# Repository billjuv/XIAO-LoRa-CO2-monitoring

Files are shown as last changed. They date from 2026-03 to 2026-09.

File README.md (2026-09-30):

# XIAO/LoRa/SCD41 CO₂ Monitoring System
> 🍄 One of several related projects. See the full list at **[billjuv.github.io](https://billjuv.github.io)**.

A wireless CO₂, temperature, and humidity monitoring system for mushroom grow operations, using LoRa radio to send sensor data to a central MQTT broker — no WiFi is required on the sensor node. In this project, the remote location is a mushroom grow facility in Nevada, and the local network names and device names used throughout are examples — substitute your own network and device names as appropriate.

---

## Table of Contents

- [Overview](#overview)
- [Bill of Materials](#bill-of-materials)
- [Hardware Setup](#hardware-setup)
- [Firmware](#firmware)
- [LoRa Gateway (OMG)](#lora-gateway-omg)
- [MQTT Data Pipeline](#mqtt-data-pipeline)
- [Node-RED Dashboard](#node-red-dashboard)
- [InfluxDB & Grafana](#influxdb--grafana)
- [SCD41 Calibration (FRC)](#scd41-calibration---frc)
- [OTA Firmware Updates](#ota-firmware-updates)
- [Known Issues & Lessons Learned](#known-issues--lessons-learned)
- [Future Enhancements](#future-enhancements)
  
---

## Overview

This project monitors CO₂ levels in the incubation and fruiting areas of a mushroom grow operation. At this time, three identical sensor units are deployed (though only two are documented below), each transmitting wirelessly over LoRa to a central gateway. The sensor nodes can be run on battery power and need to be moved outdoors for recalibration, or while determining optimal placement. 

**Why LoRa instead of WiFi?**  

WiFi has its challanges in the twin metal shipping containers in this mushroom grow space. I want to test the reliability and range of LoRa (not LoRaWAN) in this situation and hopefully be ready for future growth. Ultimately, I wish to expand this method to more remote areas of the farm as well. **Note:** The LilyGo T3 LoRa32 running OpenMQTTGateway does require WiFi to send the data recieved to the MQTT broker.

**Why Sensirion SCD41 instead of the Atlas Scientific EZO-CO₂?**  

The EZO sensors require lab-grade reference gases for recalibration and proved unreliable in this environment (one of two failed and the other EZO-CO2 sensor readings seem considerably lower than expected). The SCD41 supports Forced Recalibration (FRC) using outdoor air (~425 ppm), making field recalibration practical with just a short trip outside. Cost is also an obvious factor.
**Note:** The SCD41 has a maximum CO₂ reading of 5000 ppm, whereas the Atlas EZO-CO₂ max is 10,000 ppm. This should not be a problem in most cases as you want to keep the CO₂ level in fruiting well below 1000. During incubation, levels of 10,000 to 20,000 ppm are common - which is beyond the EZO's capabilities as well.

### System Architecture

```
[XIAO ESP32S3 + SCD41]
        |
        | LoRa (915 MHz)
        ↓
[LilyGo T3 LoRa32 running OpenMQTTGateway]
        |
        | MQTT (WiFi)
        ↓
[Mosquitto on Raspberry Pi 4]
        |
        ├── Node-RED  (dashboard, FRC commands, watchdog alerts)
        └── InfluxDB  (time-series storage → Grafana)

```

**Why InfluxDB/Grafana instead of Mycodo?** 

[Mycodo](https://kizniche.github.io/Mycodo/) could be installed in place of the InfluxDB/Grafana programs if desired. I started with Mycodo but found, in this operation, Node-RED and Flowfuse Dashboard 2.0 offered all the functionality needed with a better control dashboard on a mobile phone. All I ended up using Mycodo for was the built-in InfluxDB database and graphs. I switched over to stand-alone InfluxDB/Grafana programs for less overhead and prettier graphs.

---

## Bill of Materials

| Component | Part | Source |
|---|---|---|
| MCU + LoRa | Seeed Studio XIAO ESP32S3 + Wio-SX1262 LoRa B2B Kit | [Seeed Studio](https://www.seeedstudio.com/Wio-SX1262-with-XIAO-ESP32S3-p-5982.html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) |
| CO₂/Temp/RH Sensor | Adafruit SCD41 | [Adafruit](https://www.adafruit.com/product/5190?srsltid=AfmBOooh3oM7GaWI46jUPZLEENWeh_0F4iTKuAPATtS-eD_7WIwIb3Oz) |
| Battery Monitor | Adafruit MAX17048 LiPoly / LiIon Fuel Gauge | [Adafruit](https://www.amazon.com/dp/B0D7CL94L2?ref_=ppx_hzsearch_conn_dt_b_fed_asin_title_2&th=1) |
| Battery | 3.7V / 1800mAh LiPo | [Amazon](https://www.amazon.com/YELUFT-Rechargeable-Protection-Compatiable-Development/dp/B0F1J7359H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) |
| LoRa Gateway | LilyGo T3 LoRa32 v1.6.1 (915mHz)| [AliExpress](https://www.aliexpress.us/item/2251832685763835.html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) |
| USB-C connector | Female waterproof Type-C panel mount | [Amazon](https://www.amazon.com/dp/B0D7CL94L2?ref_=ppx_hzsearch_conn_dt_b_fed_asin_title_2&th=1) |
| Waterproof On/Off Switch | 12mm push-on, push-off IP65 | [Amazon](https://www.amazon.com/dp/B0D5CVJGYF?ref_=ppx_hzsearch_conn_dt_b_fed_asin_title_4&th=1) |
| PTFE filter membranes | 20mm, 0.3µm pore, hydrophobic, adhesive-backed | [Amazon](https://www.amazon.com/dp/B09LD119PF?ref_=ppx_hzsearch_conn_dt_b_fed_asin_title_15&th=1) |
| Sensor cable | 22/4 Stranded/Shielded (connectors below added)| Spare shop supplies |
| Sensor cable connectors | 2.54 Female JST XH "Dupont" connectors| [Amazon](https://www.amazon.com/dp/B0897KGG59?ref_=ppx_hzsearch_conn_dt_b_fed_asin_title_108) |
| Enclosure (MCU/battery) | Custom 3D printed box | [See Enclosures.md](Enclosures.md) |
| Enclosure (sensor) | Custom 3D printed box | [See Enclosures.md](Enclosures.md) |

RE: Vendors - Seeed Studio and Adafruit are good sources for products linked, but [Digikey](https://www.digikey.com) carries these items as well at similar pricing, but web pages chosen were better.

> ⚠️ As with any Lora or RF device, be sure to attach the antenna prior to sending any signals. Damage can occur

> ⚠️ Check battery plug polarity (2.0 JST) - all I had received are reversed from normal. Easy to correct, but do it before you let the smoke out.

## Datasheets
[Sensirion SCD4x](Extras/Datasheets/Sensirion_SCD4x_Datasheet.pdf)

[Adafruit-SCD40/41](Extras/Datasheets/adafruit-scd-40-and-scd-41.pdf)

[Adafruit-MAX17048](Extras/Datasheets/adafruit-max17048-lipoly-liion-fuel-gauge-and-battery-monitor.pdf)

---

## Hardware Setup

### Enclosure Design

The sensor unit is split into two separate 3D-printed boxes connected by a short cable (under 1 meter):

Separating the sensor from the electronics keeps heat from the MCU and LoRa module away from the SCD41, which improves temperature reading accuracy.

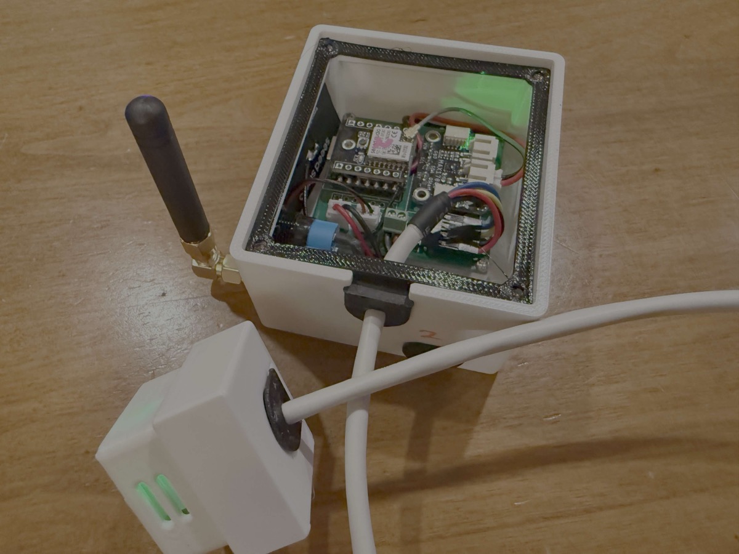
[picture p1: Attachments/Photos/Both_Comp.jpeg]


- **Main box** — contains the XIAO ESP32S3 + Wio-SX1262, MAX17048, and LiPo battery(under PCB). Houses the waterproof USB-C connector for charging and wired power as well as a button to disconnect battery power if total shutdown is desired.

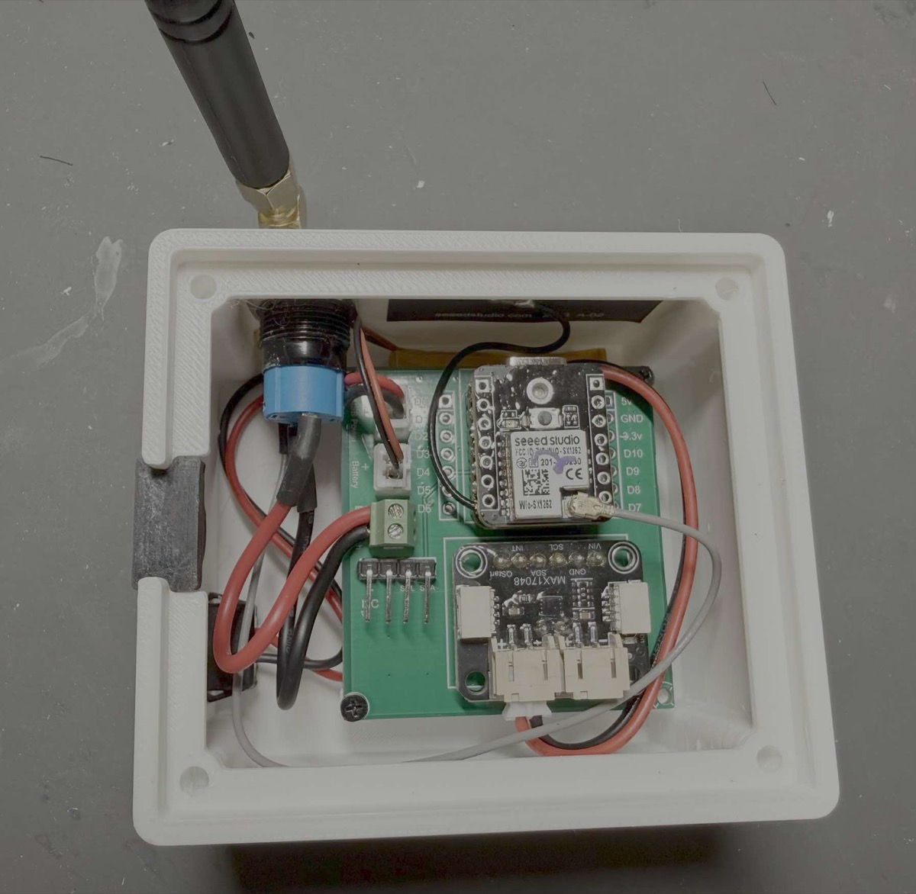
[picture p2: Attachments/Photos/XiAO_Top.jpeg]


(Threaded inserts and lid not shown)

- **Sensor box** — contains the SCD41 only, with a replaceable hydrophobic PTFE membrane filter over the sensor openings (not shown). This box can be positioned for optimal airflow independent of power constraints.

The design of the SCD enclosure takes into account the air flow recommendations from the Sensirion Datasheet.

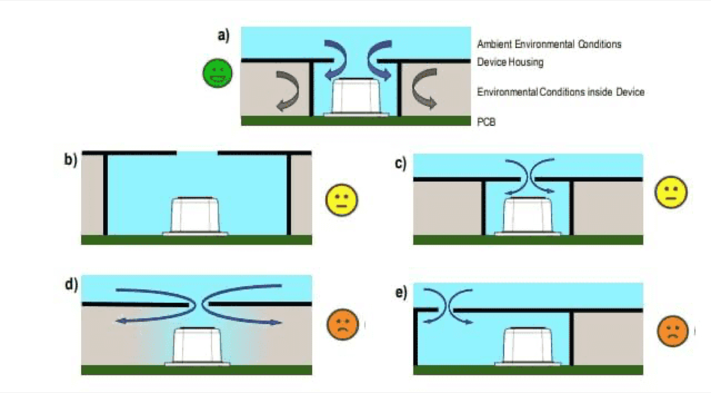
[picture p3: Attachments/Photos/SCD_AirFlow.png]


The foam around the sensor improves the seal (below).

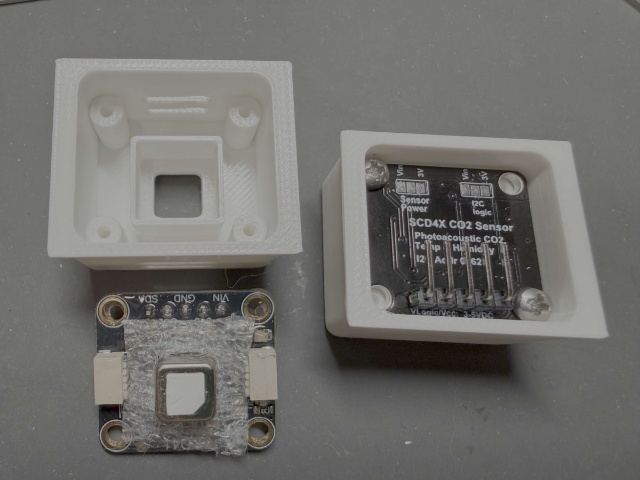
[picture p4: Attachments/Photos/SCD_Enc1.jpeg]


The cable enters from the top to allow hanging with the sensor facing down. The cable grommet shown is 3D printed out of TPU to keep out moisture. Stick-on PTFE membranes are to be placed over vent holes on sides and bottom and replaced as needed.

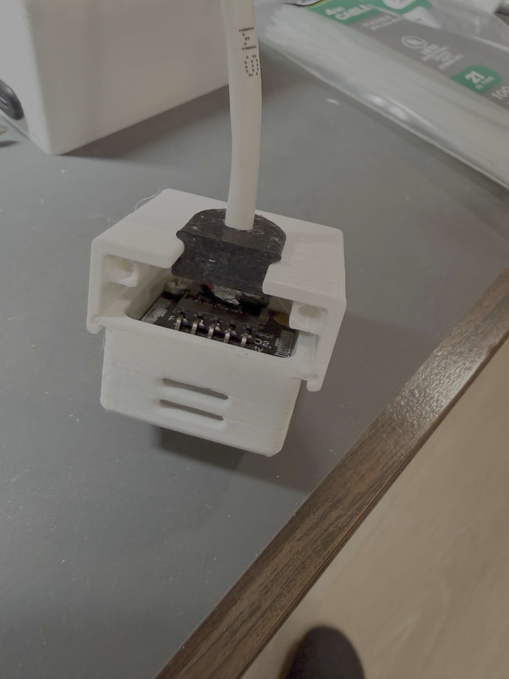
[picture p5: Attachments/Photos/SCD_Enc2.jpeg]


(Threaded inserts and end-cap not shown)

### Pin Mapping

| Function | XIAO ESP32S3 Pin |
|---|---|
| SX1262 NSS (chip select) | 41 |
| SX1262 DIO1 | 39 |
| SX1262 RST | 42 |
| SX1262 BUSY | 40 |
| Status LED | 48 |
| SCD41 SDA (I2C) | 5 (default) |
| SCD41 SCL (I2C) | 6 (default) |
| MAX17048 SDA | 5 (shared I2C bus) |
| MAX17048 SCL | 6 (shared I2C bus) |

> **Note:** The XIAO ESP32S3 + Wio-SX1262 B2B Kit uses a custom pin mapping for the SX1262 that differs from separately purchased boards. The values above are specific to the B2B kit variant.

### Wiring / Schematic

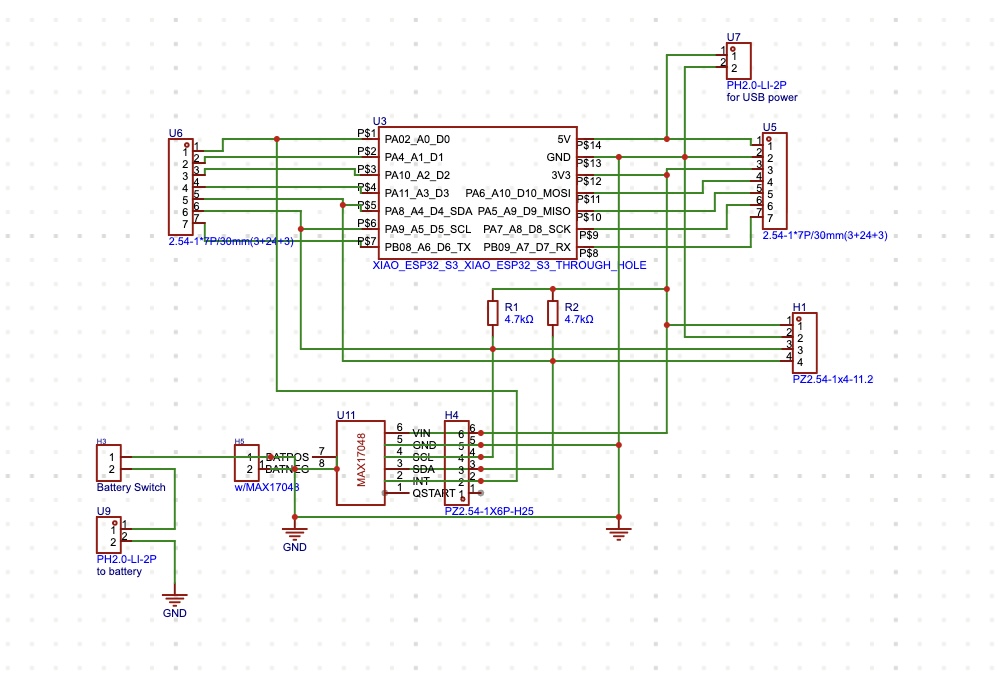
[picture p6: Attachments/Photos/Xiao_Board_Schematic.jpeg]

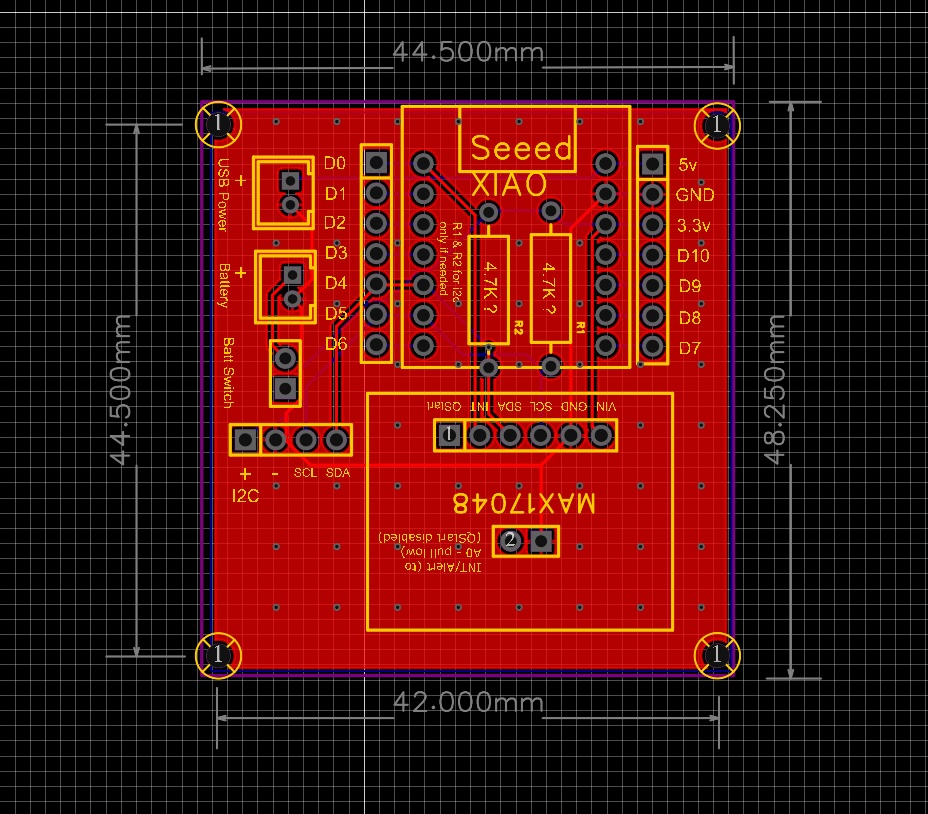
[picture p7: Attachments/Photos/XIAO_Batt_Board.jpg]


> **Note:** Gerber files located in Extras Folder (Extras/Gerber Files/XIAO_Gerber_PCB1.zip)

For other uses, board has additional access to XIAO GPIO pins if needed. Resistors for i2c (under XIAO) usually not needed but available. XIAO MCU board provides built-in battery charging circuitry. **Note:** The above board uses JST 2.0 connectors

- Battery life with the 1800mAh LiPo exceeded 15 hours in testing before recharging. I chose this battery to give enough life during initial optimal placement determination. In practice, the units are typically kept on wired USB-C power when stationary, with battery used mainly for outdoor FRC recalibration runs.

> ⚠️ LiPo batteries often have battery polarity reversed and can cause damage (easy to swap pins for the JST 2.0 connector).

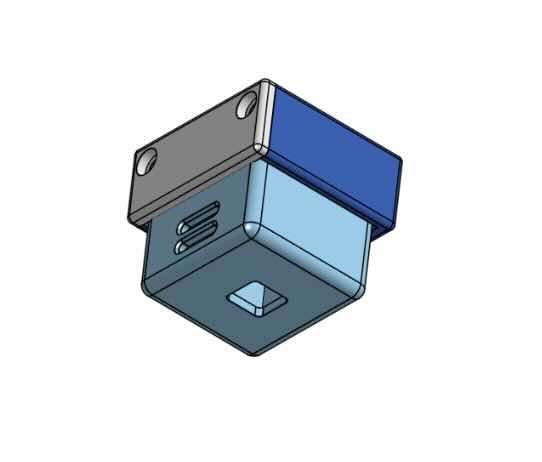
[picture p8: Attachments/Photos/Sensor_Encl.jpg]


### Enclosures & 3D Printing
Both enclosures, the cable grommet, and the lid gasket are custom 3D-printed parts. Full documentation including Onshape links, print settings, materials, and assembly notes is in [ENCLOSURES.md](Enclosures.md).

---

## Firmware

### Prerequisites

- [VSCode](https://code.visualstudio.com/) with [PlatformIO extension](https://platformio.org/)
- A USB-C cable for initial flashing

### Repository Files
- src/main.cpp — Main firmware source
- platformio.ini — PlatformIO build configuration

### platformio.ini

```ini
[env:seeed_xiao_esp32s3]
platform = espressif32@6.6.0
board = seeed_xiao_esp32s3
framework = arduino
monitor_speed = 115200
monitor_filters = time
build_flags =
    -DCORE_DEBUG_LEVEL=5
board_build.stack_size = 16384
board_build.f_cpu = 240000000L
board_build.f_flash = 80000000L
lib_deps =
    Sensirion I2C SCD4x @ ^1.0.0
    bblanchon/ArduinoJson @ ^7.4.2
    sensirion/Sensirion Core @ ^0.7.2
    jgromes/RadioLib @ ^7.5.0
    adafruit/Adafruit MAX1704X @ ^1.0.2
```

### Device Naming

Each unit auto-generates a unique name from its full 6-byte MAC address. Set the base name at the top of `main.cpp`:

```cpp
#define DEVICE_BASE_NAME "LoRa_XIAO1"   // Change for each unit
```

The result will be something like `LoRa_XIAO1_2C02A7D4DB1C`. This name is used as the MQTT `value` field and as the target address for remote commands.

> ⚠️ Using only the last 3 MAC bytes caused duplicate names on boards from the same batch. The full 6-byte MAC is required. Note that the MAC bytes are reported in reverse order — the actual MAC address for the example above would be 1C:DB:D4:A7:02:2C.

### Key Firmware Behaviors

| Behavior | Details |
|---|---|
| Measurement interval | 31 seconds (odd numbers to avoid possible packet collisions between units)*|
| ASC (auto-calibration) | Disabled on every boot and persisted to EEPROM |
| LoRa TX mode | Asynchronous — sensor can still receive commands while transmitting |
| Battery monitoring | MAX17048 detected at startup; if absent, battery fields report 0 / UNKNOWN |
| CPU frequency | Locked to 240 MHz — prevents light sleep from interfering with LoRa interrupts |
| FRC duplicate guard | Ignores repeated FRC commands with the same target within 30 seconds |

*During development, 9 seconds (being a non-round number) was found to make accidental sync less likely to persist even if boards start up at the same time. Time was increased to 31 seconds for production.

---

### Remote Commands (via LoRa)

Commands are sent from Node-RED through the OMG gateway as JSON, targeted by device name:

| Command | JSON payload example |
|---|---|
| Forced recalibration | `{"target":"LoRa_XIAO1_2C02A7D4DB1C","frc":420}` |
| Set temperature offset | `{"target":"LoRa_XIAO1_2C02A7D4DB1C","temp_offset":2.5}` |
| Get temperature offset | `{"target":"LoRa_XIAO1_2C02A7D4DB1C","get_temp_offset":true}` |
| Set altitude | `{"target":"LoRa_XIAO1_2C02A7D4DB1C","altitude":1500}` |
| Get altitude | `{"target":"LoRa_XIAO1_2C02A7D4DB1C","get_altitude":true}` |
| Trigger OTA update | `{"target":"LoRa_XIAO1_2C02A7D4DB1C","ota":true}` |

> The OMG gateway wraps outgoing commands in a `message` field. The firmware handles both wrapped and unwrapped formats for flexibility.

---

### Flashing

1. Connect the XIAO via USB-C
2. Open the project in VSCode/PlatformIO
3. Click **Upload** (or `pio run -t upload`)
4. Open Serial Monitor at 115200 baud to verify startup

---

## LoRa Gateway (OMG)

**Hardware:** LilyGo T3 LoRa32 v1.6.1  
**Firmware:** [OpenMQTTGateway](https://docs.openmqttgateway.com/) v1.8.1

OMG Configuration
The LilyGo T3 LoRa32 was flashed with OpenMQTTGateway v1.8.1 using their web installer — no Arduino IDE or PlatformIO required. Key configuration settings:

| Setting | Value |
|---|---|
| MQTT Broker | MushRmPi (Raspberry Pi running Mosquitto)
| Topic Prefix | OMGhome 
| Gateway Name | OMG_LORA_MOAPA
| WiFi | Required for MQTT connection to broker

The LoRa radio parameters (frequency, SF, bandwidth, etc.) are configured via MQTT commands after flashing — see the OMG LoRa documentation for details. The parameters used in this project are listed in the LoRa Radio Parameters table below.

### LoRa Radio Parameters

Both the sensor firmware and OMG must use identical settings:

| Parameter | Value |
|---|---|
| Frequency | 915.0 MHz (US) |
| Spreading Factor | SF7 |
| Bandwidth | 125 kHz |
| Coding Rate | 4/5 |
| Preamble Length | 8 |
| Sync Word | 0x12 (private network) |
| CRC | Enabled |

> **Sync word 0x12** keeps traffic off from public LoRaWAN networks. Do not use 0x34.

---

## MQTT Data Pipeline

### Incoming Telemetry (OMG → MQTT)

OMG publishes recieved packets to:
```
OMGhome/OMG_ESP32_LORA/LORAtoMQTT
```

Example payload:
```json
{
  "value": "LoRa_XIAO1_2C02A7D4DB1C",
  "co2": 587,
  "temp": 20.77,
  "hum": 35.36,
  "rssi": -38,
  "snr": 10.0,
  "batt_volt": 4.09,
  "batt_percent": 90.2,
  "batt_crate": -3.95,
  "batt_status": "OK",
  "crc_errors": 42
}
```
**Note:** CRC errors in LoRa telemetry
Each sensor unit tracks and reports cumulative CRC errors — packets received but discarded due to radio corruption or collision. Some level of CRC errors is normal, particularly in metal-walled environments. High counts relative to valid packets received may indicate range, interference, or collision issues worth investigating.

### Node-RED Parsed Topics

Node-RED subscribes to the OMG topic, parses by device name, and republishes to per-device topics:

```
LoRa_NodeRed/LoRa_XIAO1_2C02A7D4DB1C/co2
LoRa_NodeRed/LoRa_XIAO1_2C02A7D4DB1C/temp
LoRa_NodeRed/LoRa_XIAO1_2C02A7D4DB1C/hum
LoRa_NodeRed/LoRa_XIAO1_2C02A7D4DB1C/batt_percent
... etc.
```

### Outgoing Commands (Node-RED → OMG → LoRa)

Node-RED publishes FRC and calibration commands to:
```
OMGhome/commands/MQTTtoLORA
```

Wrapped payload format required by OMG:
```json
{"message":"{\"target\":\"LoRa_XIAO1_2C02A7D4DB1C\",\"frc\":420}"}
```

---

## Node-RED Dashboard

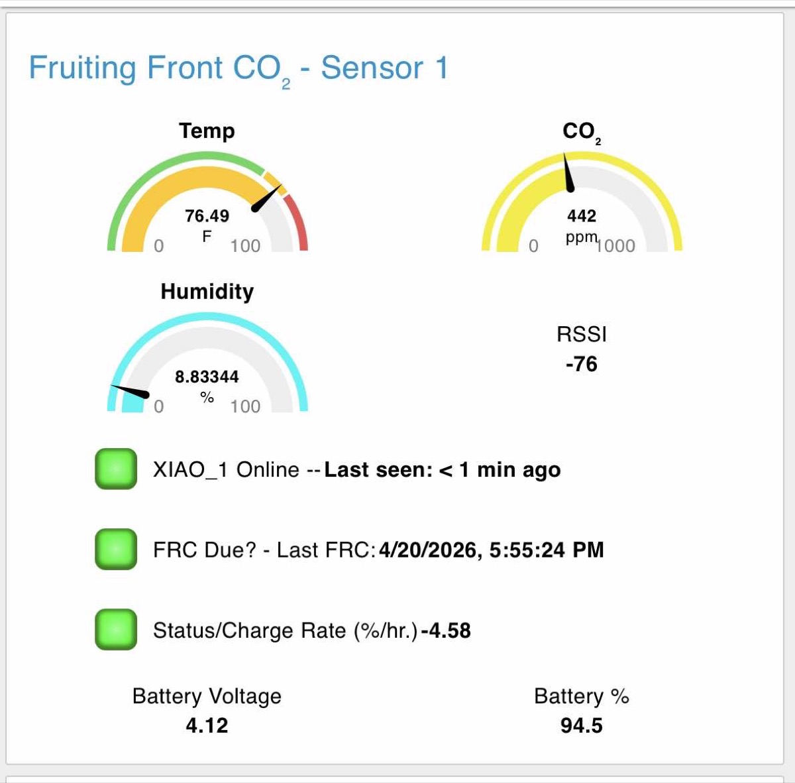
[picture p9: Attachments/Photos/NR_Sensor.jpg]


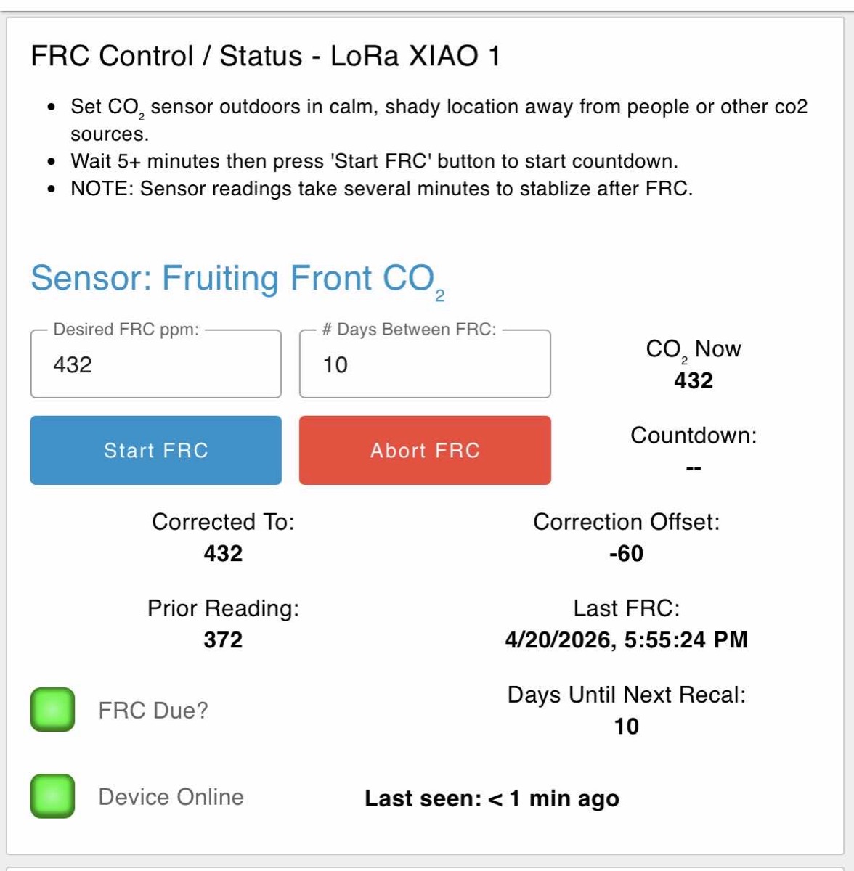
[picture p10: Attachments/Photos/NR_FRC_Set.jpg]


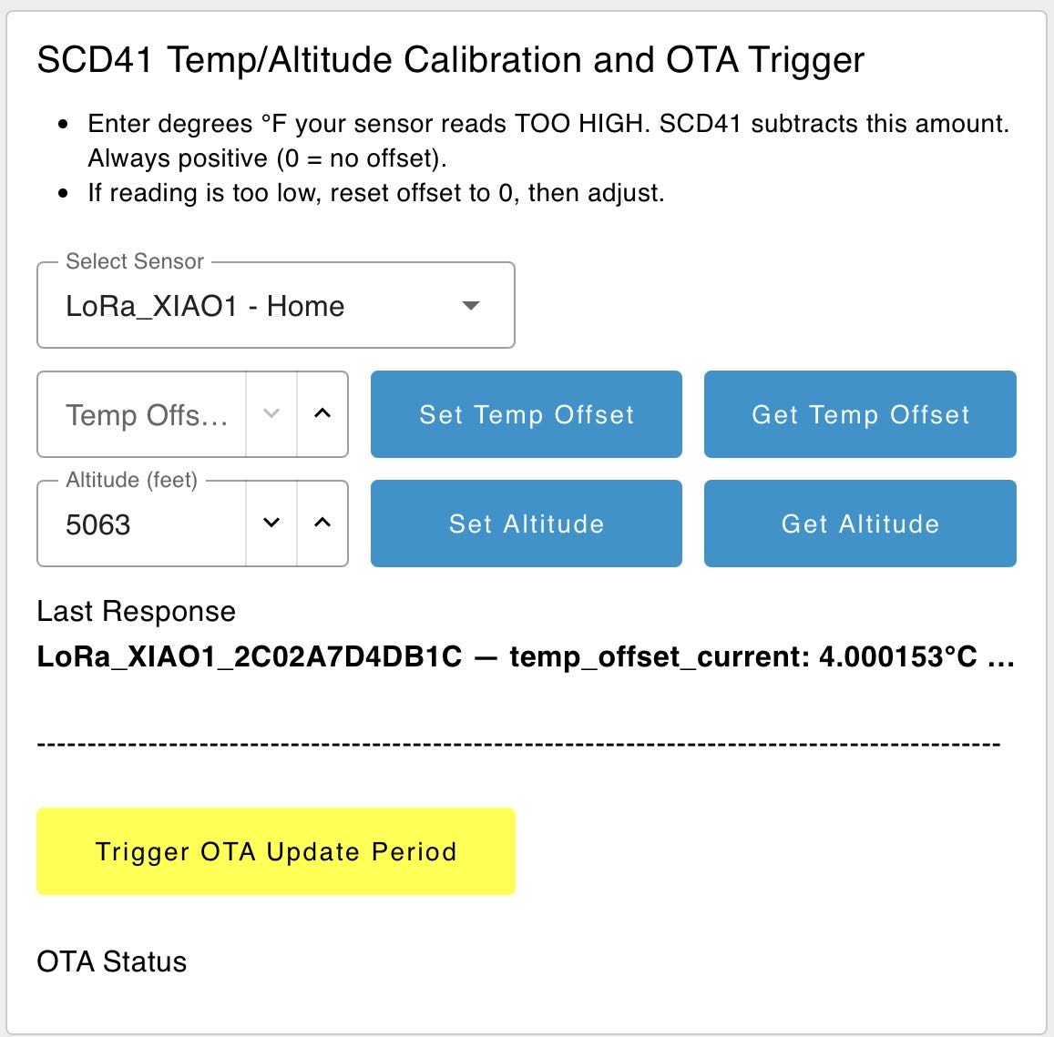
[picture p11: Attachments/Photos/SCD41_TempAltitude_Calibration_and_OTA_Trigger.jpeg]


**JSON files for all three elements are located in "Extras/NodeRED" folder** - 

Import these via Node-RED menu → Import → select file

**Platform:** Node-RED v3.1.7 with FlowFuse Dashboard 2.0

### Features

- **Per-sensor dashboard panels** — separate groups for each CO₂ unit (XIAO1, XIAO2)
- **Live CO₂, temp, and RH readings**
- **Battery status display** — voltage, percent, charge rate
- **FRC calibration controls** — countdown timer, configurable target ppm
- **Multi-send reliability** — FRC command sent 3–4 times at 2-second intervals to account for LoRa packet loss
- **Watchdog status indicator** — LED goes yellow at 5 min silence, red at 10 min, with "Last seen X min ago" text
- **Temperature and Altitude calibration** - Converted for "F" and feet. Separate group as likely only done once
- **OTA trigger button** — select target device from dropdown and press "Trigger OTA Update Period" to initiate remote firmware update

---

## InfluxDB & Grafana

**InfluxDB version:** 1.x  
**Database:** `Sensors`  
**Host:** MushRmPi (Raspberry Pi 4)

### Data Write Method

Data is written to InfluxDB via an **HTTP request node** in Node-RED (not the InfluxDB Out node). This gives direct control over the line protocol format and avoids compatibility issues with InfluxDB 1.x.

### Measurements & Fields

| Measurement | Fields |
|---|---|
| `LoRa_XIAO1_co2` | `co2`, `hum`, `temp` |
| `LoRa_XIAO2_co2` | `co2`, `hum`, `temp` |

> ⚠️ Spaces in InfluxDB measurement names cause silent write failures in line protocol. Use underscores only.

### Grafana

**Sample Grafana Visualization:** (pre-deployment)

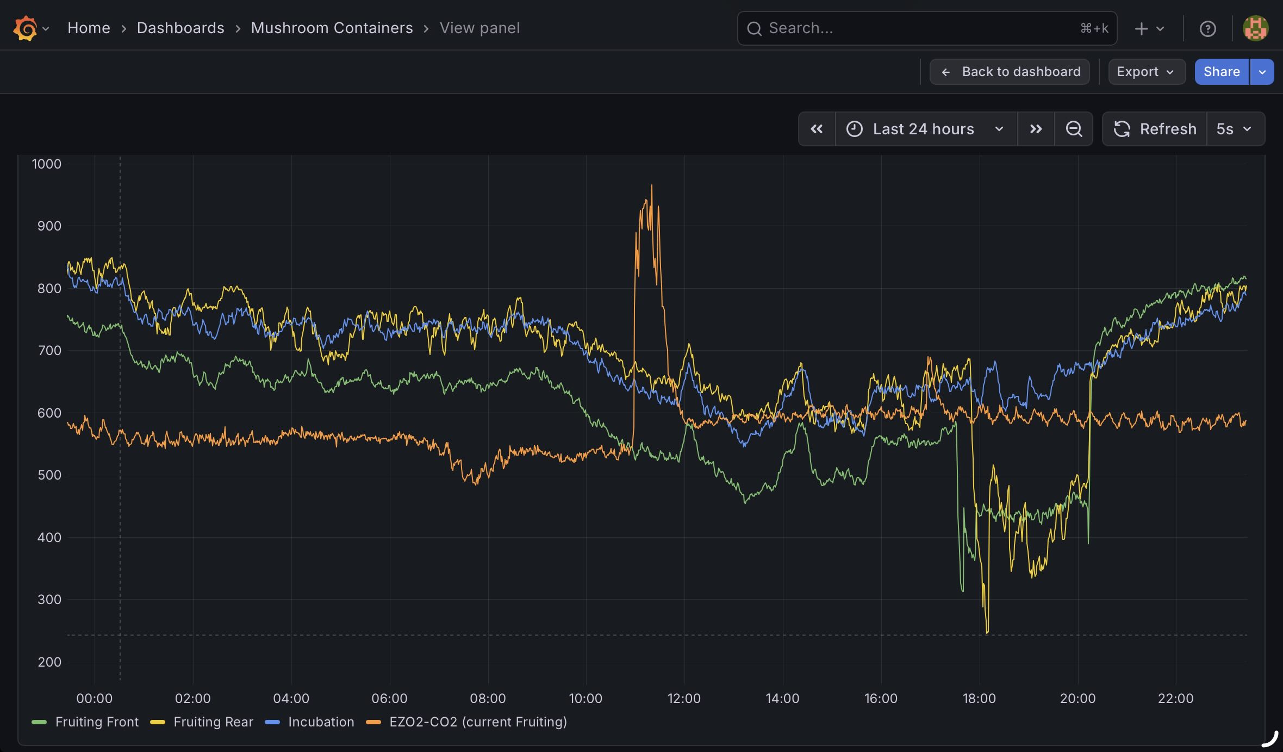
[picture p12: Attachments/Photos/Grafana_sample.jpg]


- Additional visualizations not set up yet, but could include Time-series panels for CO₂, temperature, and humidity per sensor

---

## SCD41 Calibration - FRC
[(See the Calibration.md file for more info)](CalibrationGuide.md)

The SCD41 uses **Forced Recalibration (FRC)** rather than Automatic Self-Calibration (ASC). ASC assumes regular exposure to fresh outdoor air (~420 ppm), which does not happen in a sealed mushroom grow environment. ASC is disabled in firmware and the setting is persisted to EEPROM.

### When to Recalibrate

Recalibrate every **7–10 days**, or any time readings seem inconsistent.

Signs calibration may have drifted:
- CO₂ readings are unusually high or low at rest
- Readings between the two units diverge significantly
- Indoor readings match or exceed expected fruiting-room levels even when the room has been aired out

### FRC Procedure

1. **Check battery** — ensure adequate charge before going outdoors (dashboard battery indicator)
2. **Take the sensor unit outdoors** — find an open area away from vehicle exhaust, HVAC vents, and any CO₂ sources; ideally a light wind
3. **Wait 5–10 minutes** — allow the sensor to equilibrate to outdoor air. Watch the live CO₂ reading on the dashboard stabilize
4. **Note the outdoor CO₂ reading** — typical outdoor air is 420–435 ppm. If possible, check for nearby air monitoring web portals for a current reference value 
5. **Enter the target value** — on the Node-RED FRC panel, enter the current outdoor CO₂ reference value (typically 420 ppm)
6. **Start the countdown** — the dashboard timer will count down and then send the FRC command automatically (sent 3–4 times for reliability)
7. **Confirm success** — the sensor will transmit an `frc_applied: true` confirmation. The dashboard will display the result
8. **Return the sensor** to the grow room and allow 20–30 minutes for readings to stabilize

> **Important:** The sensor must be in stable outdoor conditions *before* the FRC command is sent (5 minutes minimum). The dashboard waits 15 seconds before executing the calibration after receiving the command. The new readings will not be immediately noticable, it will take several minutes to stablilize.

### Reference CO₂ Values

| Condition | Expected CO₂ |
|---|---|
| Outdoor air (typical) | 420–435 ppm |
| Indoor office/home | 600–1000 ppm |
| Mushroom incubation room | 10000–20000+ ppm* |
| Mushroom fruiting room | 500–1500 ppm (species-dependent) |
*Values commonly mentioned on Internet as optimum - unverified

---

## OTA Firmware Updates
[(See the OTA_Guide.md file for full instructions)](OTA_Guide.md)

Once deployed, firmware updates can be pushed to any sensor unit remotely — no USB cable or physical access required. A LoRa command sent from Node-RED triggers a 3-minute WiFi OTA window on the target device. The update is then pushed from a terminal or command prompt using a shell script in the `ota/` folder. The device reboots automatically and resumes normal LoRa operation.

The Node-RED Sensor Calibration dashboard includes a **Trigger OTA Update Period** button that works alongside the existing device selector — select the target unit and press the button. A status confirmation appears on the dashboard when the device has opened its OTA window.

For remote Nevada devices, updates are delivered over Tailscale via the Nevada Raspberry Pi subnet router — no site visit needed.

> See `ota/` folder for per-device upload scripts and `include/secrets.h.example` for WiFi and OTA password configuration.

---

## Known Issues & Lessons Learned

**Duplicate device names from same-batch boards**  
The full 6-byte MAC is used for device naming, but the bytes are reported in reverse order compared to what your router or network tools will show. Using only the last 3 bytes of the MAC address caused two boards to get identical names. Fixed by using the full 6-byte MAC.

**Spaces in InfluxDB measurement names**  
Measurement names containing spaces cause silent write failures in InfluxDB line protocol. Use underscores throughout.

**ASC re-enables after reboot if not persisted**  
`setAutomaticSelfCalibrationEnabled(0)` must be followed by `persistSettings()` or ASC will re-enable on next power cycle.

**FRC must be sent multiple times**  
LoRa packet loss probability is non-trivial. The Node-RED dashboard sends the FRC command 3–4 times at 2-second intervals. The firmware deduplicates these with a 30-second same-target guard.

**LoRa interrupts unreliable on battery without CPU lock**  
Automatic CPU frequency scaling and light sleep interfered with the RadioLib interrupt-driven RX on battery power. Fixed by locking CPU to 240 MHz at boot.

**Simultaneous dropout of both units**  
Both XIAO units occasionally dropped off at the same time. Monitored via a Grafana State Timeline panel. Resolved — was a fluke related to power cycling and battery use at the time, not an ongoing issue.

**OTA via USB boot window not reliable**  
Initial OTA attempts using a timed WiFi window at boot were abandoned due to conflicts between the PlatformIO serial monitor and the USB port during upload. Replaced with LoRa-triggered OTA, which is more reliable and better suited to remote deployment.

---

## Future Enhancements

- Additional sensor units for expanded grow area coverage
- Grafana dashboards for long-term CO₂ trend analysis

---

*Documentation by BillJuv — part of the Nevada mushroom grow monitoring project.*  
*Public project documentation: [billjuv.github.io](https://billjuv.github.io)*

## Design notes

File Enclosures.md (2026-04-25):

# Enclosure & 3D Printing Documentation

This document covers the 3D-printed enclosures, grommets, and gasket used in the XIAO/SCD41 sensor units. CAD files are available on Onshape (public) and exported STEP and STL files are provided in the `CAD` folder of this repository.

---

## Table of Contents

- [Onshape Documents](#onshape-documents)
- [Bill of Materials](#bill-of-materials)
- [Filament & Print Settings](#filament--print-settings)
- [Parts Overview](#parts-overview)
  - [XIAO Control Enclosure](#xiao-control-enclosure)
  - [SCD41 Sensor Enclosure](#scd41-sensor-enclosure)
  - [Cable Grommet & Gasket](#cable-grommet--gasket)
- [Hardware & Assembly Notes](#hardware--assembly-notes)

---

## Onshape Documents

These documents are public and accessible to all Onshape users.
**Owned by:** BillJuv

| Document | Link |
|---|---|
| XIAO/SCD41/MAX17048 PCB | [Open in Onshape](https://cad.onshape.com/documents/322b31f4cb789d0ca7d721ed/w/ee8c4b56b1603b4e20ae5080/e/40f79fbb32535b3e9f26fa67) |
| SCD41_XIAO Enclosure v4.0 | [Open in Onshape](https://cad.onshape.com/documents/fcc89ce80f74fb06b3c73a24/w/bfc54d0a06e95b34f7452eb1/e/d634f8e0859f714640674855) |
| Cable Grommet | [Open in Onshape](https://cad.onshape.com/documents/550715f3ed90ea8fc4acac6c/w/30db51a251d38ff25dbee160/e/a918008760f5b729e8163560) |

---

## Bill of Materials

| Component | Details | Source |
|---|---|---|
| PETG Filament | Overture PETG | [Amazon](https://www.amazon.com/OVERTURE-Filament-Consumables-Dimensional-Accuracy/dp/B07PDV9RC8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) |
| TPU Filament | Overture "High Speed" TPU (95A)| [Amazon](https://www.amazon.com/dp/B08BC654PS?ref=ppx_yo2ov_dt_b_fed_asin_title&th=1) |
| Brass Threaded Inserts (2.5mm) | For lid and cap mounting | [Amazon](https://www.amazon.com/dp/B0FJXLGHY4?ref_=ppx_hzsearch_conn_dt_b_fed_asin_title_1) |
| Screws (2mm x 5mm) | PCB mounting — 2 per unit | [Amazon](https://www.amazon.com/dp/B082XXXRV6?ref_=ppx_hzsearch_conn_dt_b_fed_asin_title_3)|
| Screws (2.5mm x 5mm) | Lid and cap mounting | [Amazon](https://www.amazon.com/dp/B07YS94FFP?ref_=ppx_hzsearch_conn_dt_b_fed_asin_title_5) |

Other parts referenced are found in the Bill of Materials on the main ReadMe
---

## Filament & Print Settings

3D printing was done on a Bambu Labs A1 printer using Overture PETG filament for the enclosures and Overture High Speed TPU (95A) for the grommets and gasket. Bambu slicer profiles used were "Generic PETG" for the PETG and "Bambu TPU 95A HF" for the TPU. Part orientation was set using the Bambu slicer Auto-Orient feature. No supports are required for any part.

> **Note:** TPU cannot be loaded through the AMS — it must be fed directly. Filaments softer than 95A may not feed reliably with this printer.

PETG was chosen for its humidity resistance. TPU was chosen for the grommets and gasket for flexibility and a good seal.

---

## Parts Overview

### XIAO Control Enclosure

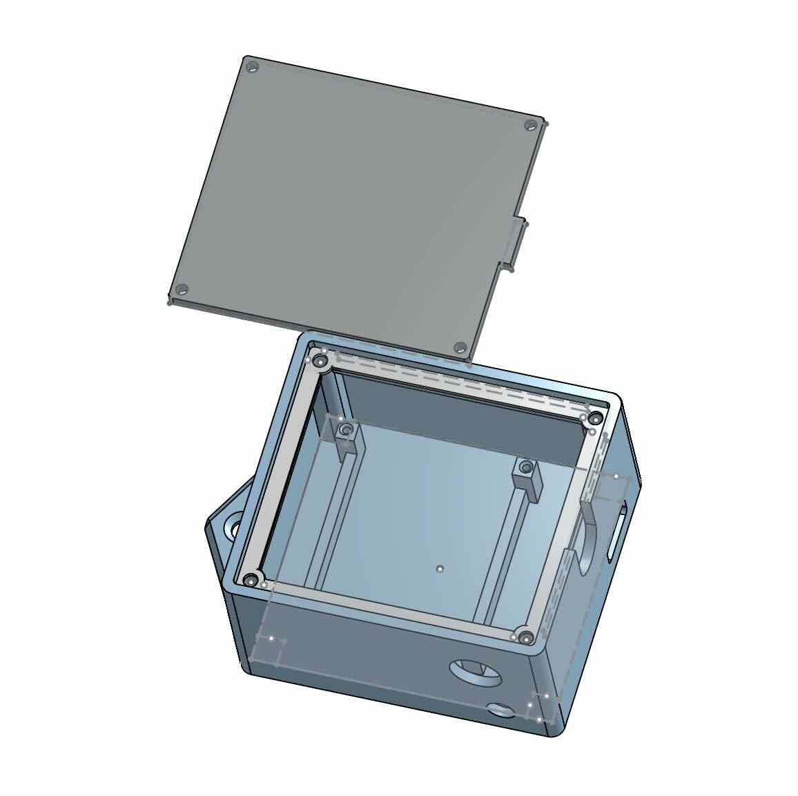
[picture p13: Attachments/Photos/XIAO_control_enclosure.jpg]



This enclosure houses the XIAO ESP32S3 + Wio-SX1262, MAX17048 fuel gauge, and LiPo battery (mounted underneath the PCB). It is designed for humidity resistance, using an IP65-rated on/off switch and a TPU cable grommet for the sensor cable entry. Additional sealing of the antenna connector and USB-C port can be achieved with conformal coating or silicone sealant if needed.

**Design details:**
- The PCB mounting posts are threaded in CAD for 2mm fine-thread screws (2 screws are sufficient)
- The lid is 3mm thick for stiffness and to apply adequate compression to the TPU gasket
- Lid is secured with 2.5mm fine-thread screws into brass threaded inserts
- A mounting tab on the side allows the box to be hung or surface-mounted

> **Note:** "Threaded in CAD" means the holes are modeled with threads — no tap tool is required. Just drive the screw directly into the printed hole.

---

### SCD41 Sensor Enclosure

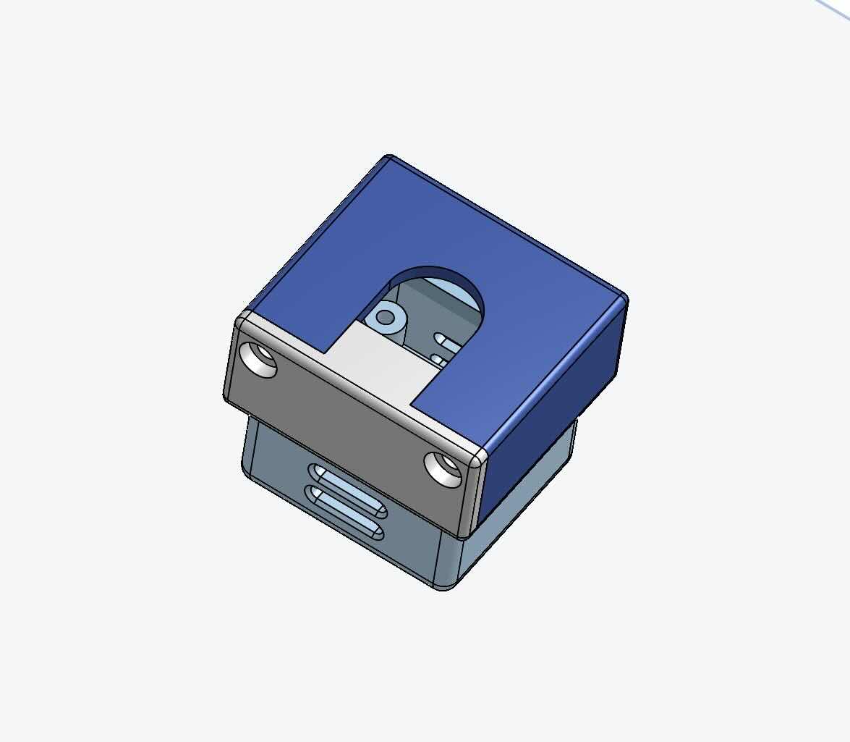
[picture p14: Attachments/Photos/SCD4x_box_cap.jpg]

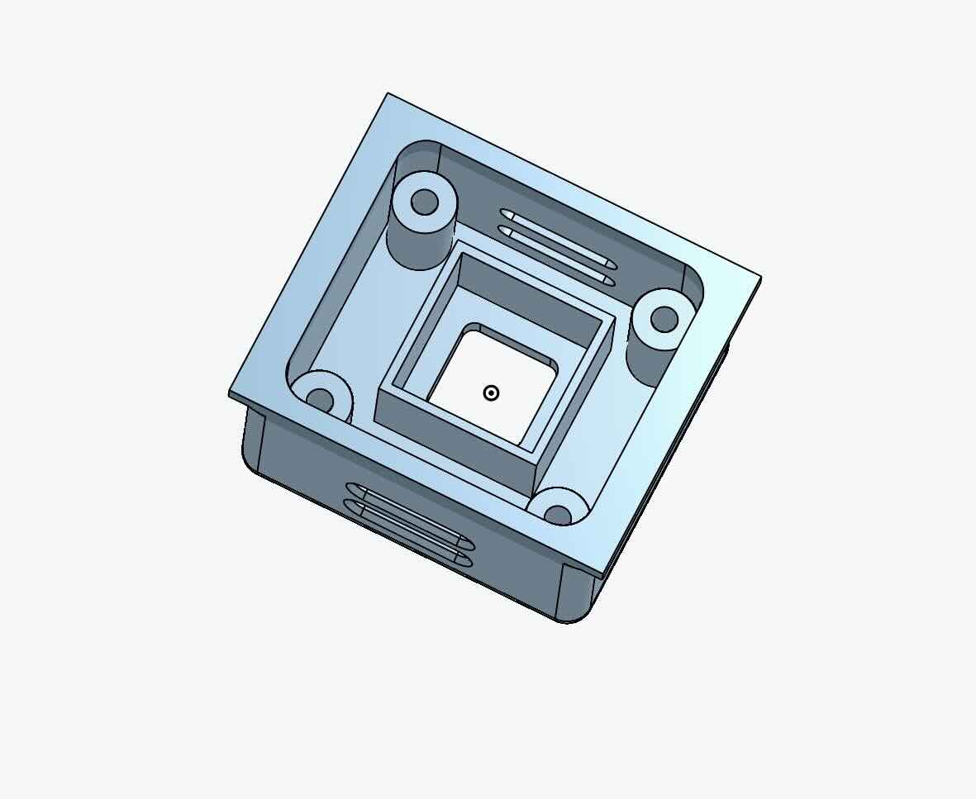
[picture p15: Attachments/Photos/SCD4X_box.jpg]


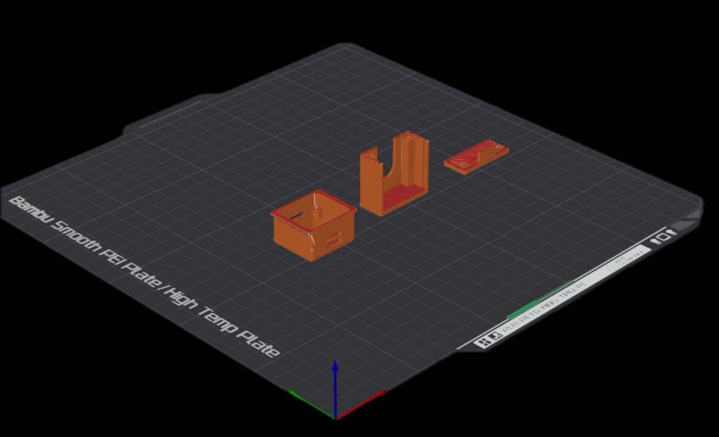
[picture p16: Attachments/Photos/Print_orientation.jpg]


This enclosure is sized to fit the Adafruit SCD41 breakout board. The cap design allows the cable to enter from the top, so the unit can be hung with the sensor facing downward for optimal airflow per the Sensirion datasheet recommendations.

**Design details:**
- Cap face screws are 2.5mm fine-thread into brass threaded inserts in the cap
- PCB post holes are threaded in CAD for 2.5mm fine-thread screws
- Self-adhesive PTFE filter membranes (20mm round) are applied over the vent holes on the bottom and two sides
- A smooth print plate is recommended — clean the surfaces with isopropyl alcohol before applying PTFE membranes
- Replace PTFE membranes as needed

---

### Cable Grommet & Gasket

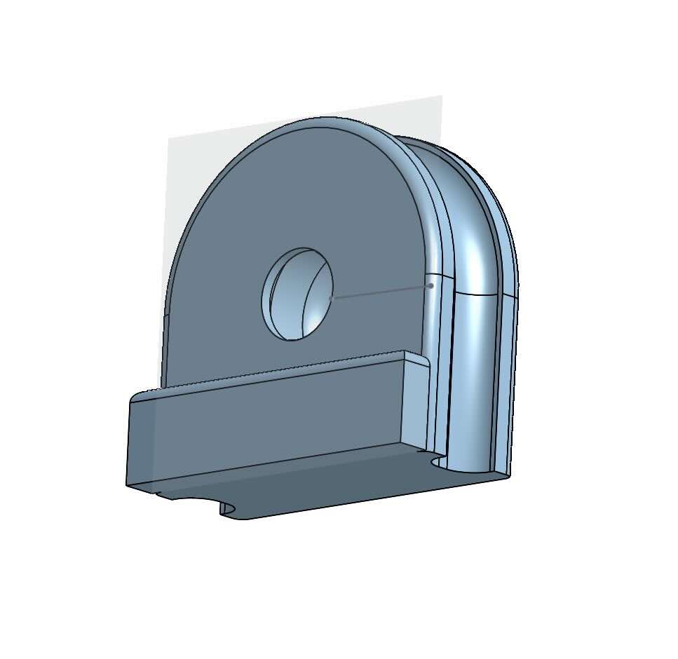
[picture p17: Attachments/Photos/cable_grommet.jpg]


The cable grommet is sized for a 4–5mm diameter cable and is used in both the XIAO control box and the SCD41 sensor cap. A slit is cut across one side of the cable hole with a utility knife to stretch ofer cable after ends are attached. The lid gasket is a separate CAD part within the enclosure assembly. Both are printed in TPU for flexibility and a weather-resistant seal.

---

## Hardware & Assembly Notes

- **Brass inserts** are installed using a soldering iron with a flat or insert tip. Set the iron to around 200–220°C and press slowly and evenly
- **Battery polarity** — LiPo batteries frequently have reversed polarity on JST connectors. Verify polarity before connecting. The JST 2.0 connector pins can be swapped easily with a pin tool
- **PTFE membranes** — clean mounting surfaces thoroughly with isopropyl alcohol before applying for best adhesion. Press firmly and allow to set before exposing to humidity
- **Assembly order** — install brass inserts before any wiring; it is easier to work with the enclosure empty

---

*Documentation by BillJuv — part of the Nevada mushroom grow monitoring project.*
*Public project documentation: [billjuv.github.io](https://billjuv.github.io)*

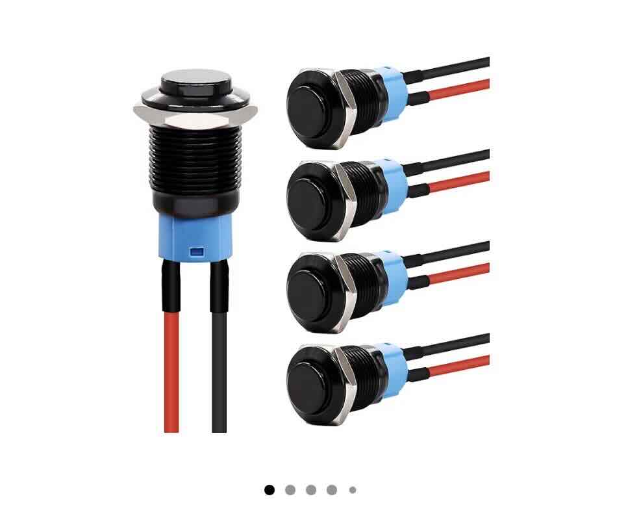
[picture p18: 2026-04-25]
Attachments/Photos/Switch.jpg

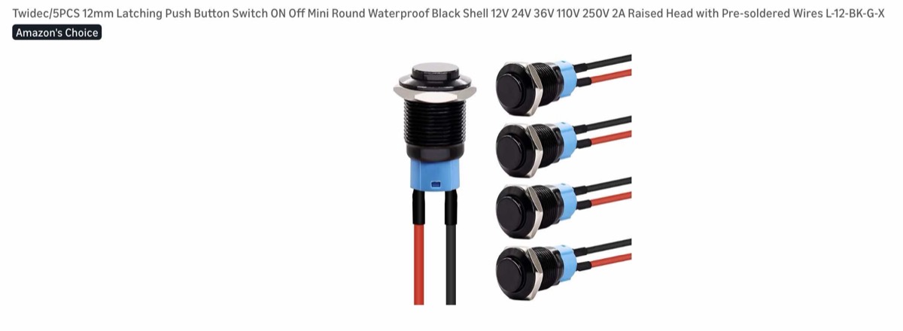
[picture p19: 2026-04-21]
Attachments/Photos/Button.jpeg

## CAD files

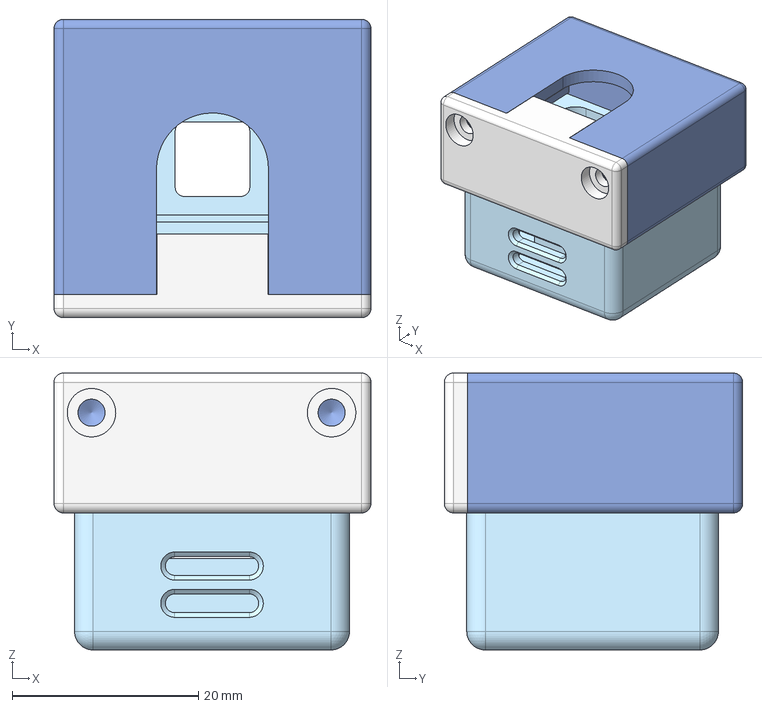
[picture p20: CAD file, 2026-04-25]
Extras/3D_Print:CAD/CAD_step/SCD41_Box_Cap_CapFace_assembly.step
34.0 x 32.0 x 29.7 mm

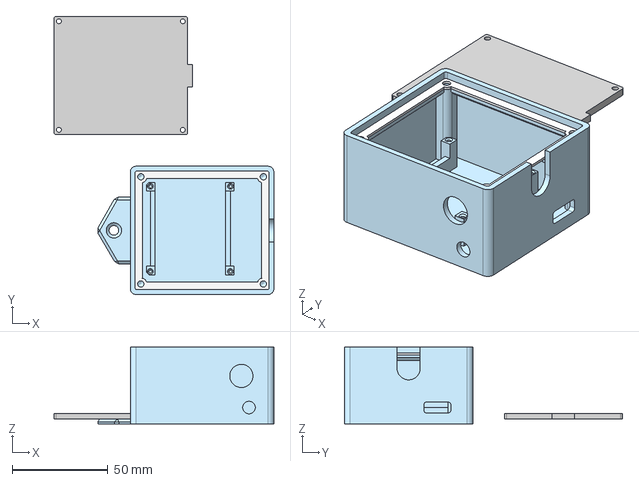
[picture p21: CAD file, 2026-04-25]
Extras/3D_Print:CAD/CAD_step/XIAO_SCD41_MAX17041_Enclosure_assembly.step
114.8 x 145.2 x 40.0 mm

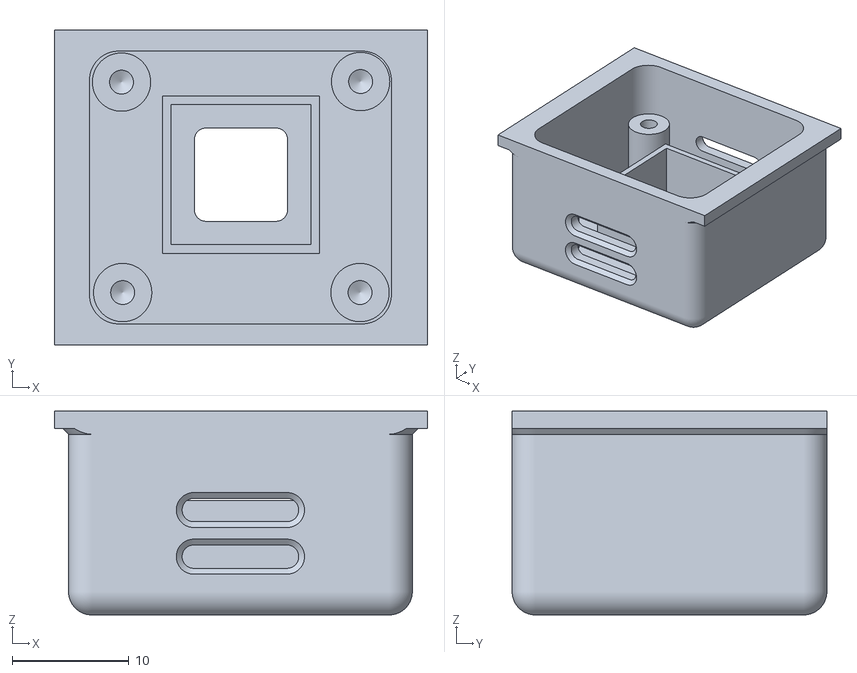
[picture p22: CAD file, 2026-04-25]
Extras/3D_Print:CAD/3D_Print_STL/SCD41_Box_Cap_CapFace_STL/SCD41_box1 - SenEnclosure.stl
32.0 x 27.0 x 17.5

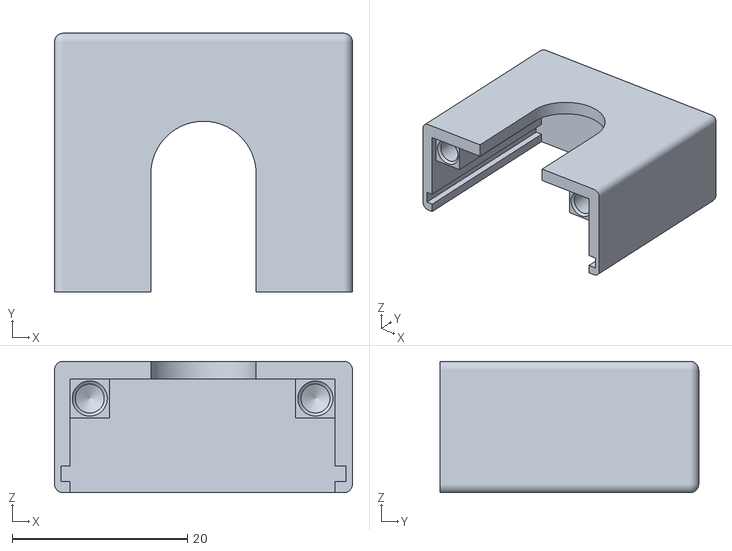
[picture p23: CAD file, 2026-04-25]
Extras/3D_Print:CAD/3D_Print_STL/SCD41_Box_Cap_CapFace_STL/SCD41_box1 - Cap.stl
34.0 x 29.5 x 15.0

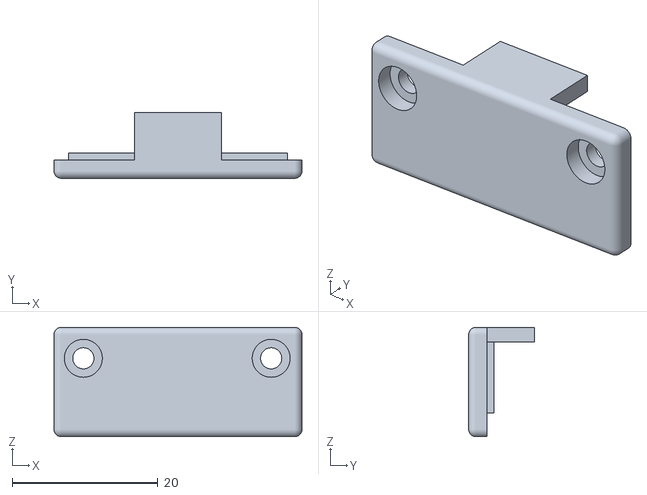
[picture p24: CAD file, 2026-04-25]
Extras/3D_Print:CAD/3D_Print_STL/SCD41_Box_Cap_CapFace_STL/SCD41_box1 - Cap Face.stl
34.0 x 9.00 x 15.0

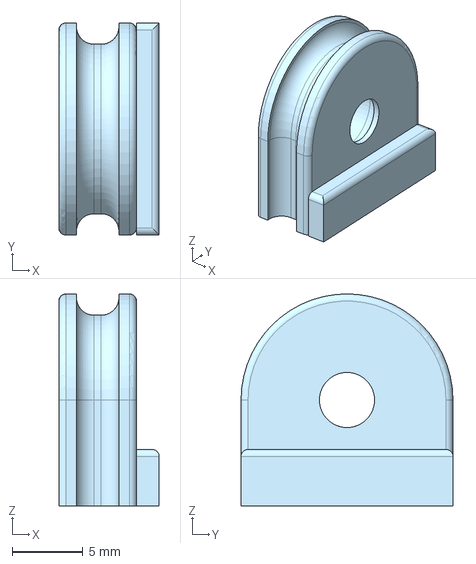
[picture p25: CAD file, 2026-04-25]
Extras/3D_Print:CAD/CAD_step/Cable_Grommet.step
7.10 x 15.0 x 15.0 mm

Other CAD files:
Extras/3D_Print:CAD/3D_Print_STL/Cable_Grommet.stl

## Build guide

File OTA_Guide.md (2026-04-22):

# OTA Firmware Update Guide
## XIAO LoRa CO2 Sensor Nodes

---

## Overview

These sensor nodes use **LoRa-triggered OTA** (Over-The-Air) firmware updates. This means:

- No USB cable or physical access to the device is needed once deployed
- A command sent from Node-RED via LoRa tells the target device to open a WiFi update window
- You push the new firmware from your computer using a Terminal command
- The device reboots automatically and resumes normal LoRa operation

### Multiple Devices

Each sensor node has a unique device name made up of a `DEVICE_BASE_NAME` (set before flashing, e.g. `LoRa_XIAO1`) plus the board's full MAC address (e.g. `LoRa_XIAO1_2C02A7D4DB1C`). This name is used to target OTA commands at a specific unit — other units on the same LoRa network will ignore commands not addressed to them.

Each device has its own OTA upload script in the `ota/` folder. You flash one device at a time.

### Multiple WiFi Networks

The firmware supports two WiFi networks. On boot into OTA mode, it tries the first network (`WIFI_SSID_1`) and falls back to the second (`WIFI_SSID_2`) if the first is not found. This allows the same firmware to work at different locations — for example, a home lab and a remote grow facility — without modification.

### Remote Updates via Tailscale

The XIAO sensor nodes themselves cannot run Tailscale. Instead, a Raspberry Pi at the remote location runs Tailscale with **subnet routing** enabled. This makes all devices on the remote local network reachable from your Mac over Tailscale, using their normal local IP addresses. You do not need to know any Tailscale-specific IP for the XIAO units — just their regular local network IP addresses, accessed through the subnet router.

---

## Platform Notes

### Mac / Linux
Terminal commands in this guide work as-is. The `chmod` command is required to make scripts executable.

### Windows
- Use **Command Prompt** or **PowerShell** instead of Terminal
- Replace `./ota/ota_xiao1.sh` with `python ota\ota_xiao1.py` (you will need to create `.py` versions of the scripts, or run the python command directly)
- The `chmod` command is not needed on Windows
- **Windows Subsystem for Linux (WSL)** users can follow the Mac/Linux instructions exactly

---

## One-Time Setup

### 1. Create your secrets.h file

Copy the example file and fill in your credentials:

```
include/secrets.h.example  →  include/secrets.h
```

Edit `include/secrets.h` with your actual values:

```cpp
#pragma once

#define WIFI_SSID_1     "YourHomeNetwork"
#define WIFI_SSID_2     "YourRemoteNetwork"
#define WIFI_PASSWORD_1 "your_home_password"
#define WIFI_PASSWORD_2 "your_remote_password"
#define OTA_PASSWORD    "your_ota_password"
```

> ⚠️ `secrets.h` is listed in `.gitignore` and will never be committed to the repo. Keep it private. Do not share it or post it anywhere.

`WIFI_SSID_1` should be the network your computer is on during development. `WIFI_SSID_2` is the fallback — typically the remote location network. The firmware tries SSID_1 first, then SSID_2.

---

### 2. Make the OTA scripts executable (Mac / Linux only)

This only needs to be done once after cloning the repo. Open Terminal and navigate to the project folder:

```bash
cd /path/to/XIAO-LoRa-CO2-monitoring
```

Then run:

```bash
chmod +x ota/ota_xiao1.sh
chmod +x ota/ota_xiao_co2_1.sh
chmod +x ota/ota_xiao_co2_2.sh
chmod +x ota/ota_xiao_co2_3.sh
```

If you see `permission denied` when running a script later, repeat the `chmod` command for that script.

---

### 3. Update the OTA scripts with correct IP addresses

Each script in the `ota/` folder contains the IP address for one device. Open each script and verify or update the `--ip` value:

- **Local devices:** Use the device's local IP address. Check your router's device list or use a network scanner app (e.g. LanScan on Mac) to find it. Setting a DHCP reservation in your router for each device's MAC address will keep the IP stable across reboots.
- **Remote devices:** Use the device's local IP address on the remote network. The remote Raspberry Pi runs Tailscale with subnet routing enabled, which makes these local IPs reachable from your Mac over Tailscale without any changes to the XIAO firmware or scripts.

---

### 4. Flash each unit with its unique DEVICE_BASE_NAME

Before the initial USB flash of each unit, open `src/main.cpp` and set:

```cpp
#define DEVICE_BASE_NAME "LoRa_XIAO1"   // change for each unit
```

Use a unique name for each board. The full device name — including MAC address — is printed to the serial monitor on every boot. Record this name and update the device table below.

---

## Flashing a Firmware Update

### Step 1 — Build the firmware first

In VS Code with PlatformIO, click the **Build** button (✓ checkmark in the bottom toolbar). Make sure it says `[SUCCESS]` before proceeding.

> ⚠️ Do not use the PlatformIO Upload button for OTA — it will close the serial monitor and attempt a USB flash. OTA uploads are done via Terminal only.

---

### Step 2 — Open two Terminal windows

**Terminal Window 1 — Serial Monitor (optional, requires USB connection):**

```bash
screen /dev/cu.usbmodem1101 115200
```

> To exit screen later: press `Ctrl+A` then `K` then `Y`

**Terminal Window 2 — OTA Upload:**

Navigate to the project folder:

```bash
cd /path/to/XIAO-LoRa-CO2-monitoring
```

---

### Step 3 — Trigger OTA mode from Node-RED

Select the target device in the **Select Sensor** dropdown on the Sensor Calibration dashboard page, then click **Trigger OTA Update Period**. This sends a LoRa command through the appropriate OMG gateway to the device.

Alternatively, the MQTT payload format is:

```json
{"message":"{\"target\":\"LoRa_XIAO1_2C02A7D4DB1C\",\"ota\":true}"}
```

Sent to MQTT topic (local gateway):
```
OMGhome/OMG_ESP32_LORA/commands/MQTTtoLORA
```

Or for Nevada devices:
```
MushLoRa/OMG_LORA_MOAPA/commands/MQTTtoLORA
```

> Only the targeted device will respond — others will ignore the command.

---

### Step 4 — Wait for OTA ready confirmation

The Node-RED OTA Status display on the dashboard will show:
```
OTA mode started on LoRa_XIAO1_2C02A7D4DB1C - 3 minute window open
```

If monitoring via USB serial:
```
✓ OTA mode command received
--- OTA Mode Triggered via LoRa ---
WiFi connected: 10.0.x.xxx
OTA ready - waiting 3 minutes...
```

You now have **3 minutes** to push the firmware.

---

### Step 5 — Run the OTA upload script

In Terminal Window 2, run the script for the target device:

```bash
./ota/ota_xiao1.sh
```

You should see:

```
Sending invitation to 10.0.x.xxx
Authenticating...OK
Uploading.......................................
```

The device reboots automatically after a successful upload and resumes normal LoRa operation within about 30 seconds.

---

## Device Reference

| Script | Device Name | Network | IP Address |
|---|---|---|---|
| ota_xiao1.sh | LoRa_XIAO1_2C02A7D4DB1C | SSID1 (local) | 10.0.1.113 |
| ota_xiao_co2_1.sh | LoRa_XIAO_CO2_1_D893A8D4DB1C | SSID2 (remote) | TBD after deployment |
| ota_xiao_co2_2.sh | LoRa_XIAO_CO2_2_B893A8D4DB1C | SSID2 (remote) | TBD after deployment |
| ota_xiao_co2_3.sh | LoRa_XIAO_CO2_3_BC1BA7D4DB1C | SSID2 (remote) | TBD after deployment |

> Update IP addresses after deployment. Remote IPs are local network addresses on the SSID2 network, reachable via Tailscale subnet routing on the Nevada Raspberry Pi.

---

## Troubleshooting

**"Permission denied" running the script (Mac/Linux):**
```bash
chmod +x ota/ota_xiao1.sh
```

**"Host not found" or "Sending invitation failed":**
- The OTA window is not open — trigger from Node-RED first and wait for confirmation before running the script
- The IP address has changed — check your router or LanScan for the current IP and update the script
- You are not on the same network as the device
- For Nevada devices: confirm Tailscale is running and connected on your Mac and that the Nevada Pi subnet router is active

**"Authentication Failed":**
- The OTA password in the script does not match `OTA_PASSWORD` in `secrets.h`
- Rebuild and re-flash via USB with matching credentials

**Device appears offline in network scanner during OTA window:**
- This is normal — the device may not respond to pings while in the OTA loop. The window is still open. Proceed with the upload script.

**OTA window closed before upload completed:**
- Trigger again from Node-RED to open a new 3-minute window
- Always build firmware before triggering OTA to avoid delays

**Device does not respond to OTA command:**
- Confirm the device name in the dropdown matches exactly (case sensitive)
- The OMG gateway must be online and connected to MQTT for LoRa commands to reach the device

---

## Nevada / Tailscale Subnet Routing Notes

For remote Nevada devices:

1. Tailscale must be installed and running on your Mac
2. Tailscale must be installed and running on the Nevada Raspberry Pi, configured as a **subnet router** advertising the local K1W1 network
3. The Nevada XIAO units connect to the K1W1 WiFi network when OTA mode is triggered
4. Use the devices' normal local IP addresses in the OTA scripts — no special Tailscale IPs needed
5. Update the `ota/` scripts and device table above after initial deployment when IP addresses are known

---

*Last updated: 2026*

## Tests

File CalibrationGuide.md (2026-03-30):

# SCD41 Calibration Guide

This guide covers the recalibration procedure for the XIAO/LoRa/SCD41 CO₂ sensor units used in the mushroom grow monitoring system.

---

## Background: Why FRC Instead of ASC?

The SCD41 sensor supports two calibration modes:

**Automatic Self-Calibration (ASC)** — The sensor automatically adjusts its baseline over time by assuming that the lowest CO₂ reading seen over a rolling 7-day window represents fresh outdoor air (~420 ppm). This works well in office or home environments where the sensor regularly sees outdoor-level air.

**Forced Recalibration (FRC)** — A manual one-time calibration performed by placing the sensor in air of a known CO₂ concentration (typically outdoors) and sending a reference value command.

**ASC is not suitable for this installation.** The sensors are deployed inside sealed mushroom grow containers where CO₂ levels regularly exceed 1000–5000 ppm and the sensor rarely if ever sees outdoor air during normal operation. ASC would cause the sensor to gradually drift its baseline upward, resulting in falsely low readings over time.

ASC is disabled in firmware on every boot and the setting is saved to the sensor's internal EEPROM so it survives power cycles.

---

## How Often to Recalibrate

Recalibrate every **7–10 days** under normal operation.

Also recalibrate if you notice:
- CO₂ readings that seem unusually high or low at rest
- A significant and growing difference between the two sensor units
- Readings that don't respond as expected when the grow room is ventilated
- After any extended power outage or sensor transport

---

## What You Need

- The sensor unit (XIAO + SCD41 assembly) with sufficient battery charge
- A phone or tablet with access to the Node-RED dashboard
- Access to outdoor air — an open area away from vehicles, HVAC exhausts, generators, or any combustion source
- A calm day is ideal; light wind is fine

---

## Step-by-Step FRC Procedure

### 1 — Check battery before going outdoors

On the Node-RED dashboard, check the battery percentage for the sensor unit you are calibrating.

- **Green / OK:** Proceed
- **Yellow / WARNING (below 20%):** Charge before calibrating if possible; the process takes 10–15 minutes outdoors
- **Red / CRITICAL (below 10%):** Charge first — do not risk the sensor losing power mid-calibration

### 2 — Take the sensor unit outdoors

Carry the sensor to an open outdoor location. Good spots:
- Away from building walls (HVAC exhaust near rooflines)
- Away from any running vehicles or generators
- At least a few feet off the ground (CO₂ is heavier than air and can pool near the ground)

### 3 — Wait for the reading to stabilize

Watch the live CO₂ reading on the dashboard. After being moved outdoors it will take several minutes to settle.

- **Wait at least 5–10 minutes** before proceeding
- You are looking for a stable reading in the **415–425 ppm** range
- If readings are higher (500+ ppm), move to a more open location and wait longer
- If readings are jumping around, allow more time to stabilize

> Typical outdoor CO₂ is currently around 420–425 ppm globally. Readings slightly above or below this are normal depending on location and conditions.

### 4 — Enter the FRC target value

On the Node-RED dashboard, navigate to the FRC panel for the sensor you are calibrating.

- Enter the **target CO₂ value** — use the current outdoor reading shown on the dashboard, rounded to the nearest 5 or 10 ppm (e.g., if reading 418 ppm, enter 420)
- Double-check you are sending to the correct sensor unit (XIAO1 or XIAO2)

### 5 — Start the calibration countdown

Press the **Start FRC** button on the dashboard.

- A countdown timer will run
- At zero, the FRC command is automatically sent **3–4 times** in rapid succession to account for possible LoRa packet loss
- The LED on the XIAO board will blink briefly when each command is received

### 6 — Confirm success

Within a few seconds of the command being sent, the sensor will transmit a confirmation packet. The dashboard will display:

| Result | Meaning |
|---|---|
| `frc_applied: true` | Calibration succeeded and was saved to EEPROM |
| `frc_applied: false` | Calibration command was received but failed — retry |
| No response | Command was not received — check LoRa signal strength (RSSI) and retry |

> If you are far from the grow facility and RSSI is weak (below −100 dBm), move closer to improve reception before retrying.

### 7 — Return the sensor and allow stabilization

- Return the sensor unit to its mounting location in the grow room
- Allow **20–30 minutes** for readings to stabilize before relying on the data
- The first few readings after returning to a high-CO₂ environment may be elevated as the sensor re-equilibrates

---

## Reference CO₂ Levels

| Environment | Typical CO₂ Range |
|---|---|
| Outdoor air | 415–425 ppm |
| Indoor home / office | 600–1000 ppm |
| Occupied room, poor ventilation | 1000–2000 ppm |
| Mushroom fruiting room | 500–1500 ppm (species-dependent) |
| Mushroom incubation / colonization | 2000–10000+ ppm |

---

## Temperature Offset Adjustment

The SCD41 measures temperature using an internal sensor. Because the MCU and LoRa radio generate heat inside the enclosure, the temperature reading may read slightly higher than actual ambient air temperature.

If you find that temperature readings are consistently offset from a known-good reference thermometer, a temperature offset can be set remotely from Node-RED without taking the sensor outdoors.

This is set in the FRC dashboard under **Temperature Offset**. A positive offset value compensates for heat from the enclosure (e.g., an offset of 2.5°C will subtract 2.5° from all reported temperature values). The setting is persisted to EEPROM.

---

## Altitude Compensation

The SCD41 uses barometric pressure compensation internally to improve CO₂ accuracy. If altitude is not set, it defaults to sea level (0 m), which will cause slightly elevated CO₂ readings at higher elevations.

The Nevada facility is at approximately **[fill in elevation in meters]** meters above sea level. This value is set once via the Node-RED dashboard under **Altitude Setting** and persisted to EEPROM. It does not need to be changed unless the sensor is relocated.

---

## Troubleshooting

**Dashboard shows no response after sending FRC**
- Verify the sensor is online (watchdog LED is green)
- Check RSSI on the dashboard — if below −100 dBm, move closer to the gateway
- The command is sent 3–4 times automatically; wait 10 seconds before retrying

**CO₂ reading doesn't change after FRC**
- The sensor needs 20–30 minutes to stabilize after returning indoors — this is normal
- If still unchanged after 30 minutes, check `frc_applied` status in the dashboard

**Outdoor reading won't stabilize below 500 ppm**
- Move further from buildings, parking areas, or any combustion sources
- On still days, CO₂ can pool in low-lying or sheltered areas — try a slightly elevated or more exposed spot

**Both sensors drift together in the same direction**
- This is a good sign — it suggests the environment is changing, not calibration error
- If both are reading low, verify the grow room CO₂ source is working as expected
- If both are reading high, check for CO₂ buildup from substrate or increasing biological activity

---

*Part of the Nevada mushroom grow CO₂ monitoring project.*
*Full project documentation: [billjuv.github.io](https://billjuv.github.io)*

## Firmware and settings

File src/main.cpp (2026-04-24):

//  LoRa XIAO SCD41 CO2 Sensor Node
//  ============================================================
//  Monitors CO2, temperature, and humidity using an Adafruit SCD41
//  sensor and transmits readings over LoRa to a LilyGo T3 LoRa32
//  running OpenMQTTGateway (OMG), which forwards data to a Mosquitto
//  MQTT broker on a Raspberry Pi. Node-RED is used for dashboards
//  and remote FRC recalibration commands sent back via LoRa.
//
//  Hardware:
//    - Seeed Studio XIAO ESP32S3 + Wio-SX1262 LoRa B2B Kit
//    - Adafruit SCD41 CO2/Temp/RH sensor (I2C, address 0x62)
//    - Adafruit MAX17048 LiPo fuel gauge (I2C, shared bus)
//    - 3.7V LiPo battery
//
//  OTA Firmware Updates:
//    OTA is triggered via a LoRa command from Node-RED — no physical
//    access to the device is required. Send the following JSON payload
//    to the OMG gateway MQTT topic:
//      Topic:   OMGhome/OMG_ESP32_LORA/commands/MQTTtoLORA
//      Payload: {"message":"{\"target\":\"<device_name>\",\"ota\":true}"}
//    The device will stop LoRa, connect to WiFi, and open a 3-minute
//    OTA window. Push firmware via PlatformIO (Upload button). The
//    device reboots automatically after a successful flash and resumes
//    normal LoRa operation. WiFi credentials and OTA password are
//    stored in include/secrets.h (not committed to the repo —
//    see include/secrets.h.example for the required format).
//
//  Before flashing: set DEVICE_BASE_NAME below to a unique name
//  for each unit (e.g. "LoRa_XIAO1", "LoRa_XIAO2"). The full
//  6-byte MAC address is appended automatically as a suffix.
//  ============================================================
//#define DEVICE_BASE_NAME "LoRa_XIAO1"   // <-- CHANGE THIS for each unit
//#define DEVICE_BASE_NAME "LoRa_XIAO_CO2_1"
//#define DEVICE_BASE_NAME "LoRa_XIAO_CO2_2"
#define DEVICE_BASE_NAME "LoRa_XIAO_CO2_3"

#include <Arduino.h>
#include <Wire.h>
#include <SensirionI2cScd4x.h>
#include <ArduinoJson.h>
#include <RadioLib.h>
#include <SPI.h>
#include <Adafruit_MAX1704X.h>
#include <WiFi.h>
#include <ArduinoOTA.h>
#include <ESPmDNS.h>
#include "secrets.h"

// --- LoRa pins (Seeed XIAO ESP32S3 + Wio-SX1262 B2B Kit) ---
// Note: These pin numbers are specific to the B2B kit and differ
// from the standalone Wio-SX1262 board.
SX1262 radio = new Module(41, 39, 42, 40); // NSS, DIO1, RST, BUSY
#define LED_GPIO 48

// --- SCD41 CO2 sensor ---
SensirionI2cScd4x scd4x;

// --- MAX17048 battery monitor ---
Adafruit_MAX17048 maxlipo;
bool batteryAvailable = false;

// --- Measurement interval ---
// 9 seconds (not 10) to avoid packet collisions between two units
// transmitting on the same LoRa frequency
const unsigned long MEAS_INTERVAL_MS = 31000;
unsigned long lastRead = 0;

// --- Last-good readings (used if sensor read fails) ---
uint16_t lastCO2 = 0;
float lastTemp = 0.0;
float lastHum  = 0.0;
float lastBattVolt = 0.0;
float lastBattPercent = 0.0;
float lastBattCRate = 0.0;

// --- FRC status tracking ---
String lastFrcStatus = "none";  // "none", "received", "success", "failed", "no_persist"
unsigned long lastFrcTime = 0;
uint16_t lastFrcTarget = 0;     // Used to reject duplicate FRC commands within 30s

// --- LoRa RX diagnostics ---
unsigned long rxRestartCount = 0;
unsigned long packetsReceived = 0;
unsigned long crcErrors = 0;

// --- Battery warning thresholds ---
const float BATTERY_WARN_PERCENT = 20.0;
const float BATTERY_CRITICAL_PERCENT = 10.0;

// --- Device name (built from DEVICE_BASE_NAME + MAC address) ---
String device_name;

// --- LoRa TX/RX buffers ---
uint8_t txBuffer[256];
uint8_t rxBuffer[256];

// --- Interrupt-driven RX/TX flags ---
volatile bool receivedFlag = false;
volatile bool transmittedFlag = false;
volatile bool isTransmitting = false;

// --- Interrupt handlers ---
#if defined(ESP8266) || defined(ESP32)
    ICACHE_RAM_ATTR
#endif
void setRxFlag(void) {
    receivedFlag = true;
}

#if defined(ESP8266) || defined(ESP32)
    ICACHE_RAM_ATTR
#endif
void setTxFlag(void) {
    transmittedFlag = true;
    isTransmitting = false;
}

void startOTAMode();

/* ================= BATTERY FUNCTIONS ================= */

bool readBattery(float &voltage, float &percent, float &crate) {
    if (!batteryAvailable) {
        return false;
    }

    voltage = maxlipo.cellVoltage();
    percent = maxlipo.cellPercent();
    crate = maxlipo.chargeRate();

    // NaN can occur with a fully charged battery
    if (isnan(voltage) || isnan(percent) || isnan(crate)) {
        Serial.println("NaN detected in battery reading");
        return false;
    }

    // Sanity check valid ranges (allow slightly over 100% as MAX17048 can report 104%)
    if (voltage < 2.5 || voltage > 4.5 || percent < 0 || percent > 110) {
        return false;
    }

    return true;
}

String getBatteryStatus(float percent, bool validReading) {
    if (!validReading || !batteryAvailable) {
        return "UNKNOWN";
    }
    if (percent <= BATTERY_CRITICAL_PERCENT) {
        return "CRITICAL";
    } else if (percent <= BATTERY_WARN_PERCENT) {
        return "WARNING";
    } else {
        return "OK";
    }
}

/* ================= SENSOR FUNCTIONS ================= */

bool readSensor(uint16_t &co2, float &temperature, float &humidity) {
    for (int attempt = 0; attempt < 3; attempt++) {
        int16_t ret = scd4x.readMeasurement(co2, temperature, humidity);
        if (ret == 0) return true;
        delay(50);
    }
    return false;
}

void disableABC() {
    // ASC (Automatic Self-Calibration) assumes the sensor regularly sees
    // outdoor air (~420 ppm). This is not the case in a mushroom grow room,
    // so ASC must be disabled and persisted to EEPROM to prevent drift.
    scd4x.stopPeriodicMeasurement();
    delay(500);

    int16_t ret = scd4x.setAutomaticSelfCalibrationEnabled(0);
    if (ret == 0) {
        Serial.println("ABC disabled successfully");
        ret = scd4x.persistSettings();
        if (ret == 0) {
            Serial.println("ABC disable setting saved to EEPROM");
        } else {
            Serial.printf("Failed to persist ABC setting, error: %d\n", ret);
        }
    } else {
        Serial.printf("Failed to disable ABC, error: %d\n", ret);
    }

    delay(500);
    scd4x.startPeriodicMeasurement();
}

/* ================= TEMPERATURE OFFSET CALIBRATION ================= */

void setTemperatureOffset(float offsetDegC) {
    Serial.printf("Setting temperature offset to %.2f °C\n", offsetDegC);

    scd4x.stopPeriodicMeasurement();
    delay(500);

    int16_t ret = scd4x.setTemperatureOffset(offsetDegC);

    bool success = false;
    if (ret == 0) {
        Serial.printf("Temperature offset set to %.2f °C\n", offsetDegC);
        ret = scd4x.persistSettings();
        if (ret == 0) {
            Serial.println("Temperature offset saved to EEPROM");
            success = true;
        } else {
            Serial.printf("Failed to persist temperature offset, error: %d\n", ret);
        }
    } else {
        Serial.printf("Failed to set temperature offset, error: %d\n", ret);
    }

    delay(500);
    scd4x.startPeriodicMeasurement();

    StaticJsonDocument<256> doc;
    doc["value"] = device_name;
    doc["temp_offset_set"] = success;
    doc["temp_offset_value"] = offsetDegC;
    doc["co2"] = lastCO2;
    doc["temp"] = lastTemp;
    doc["hum"] = lastHum;
    doc["batt_volt"] = lastBattVolt;
    doc["batt_percent"] = lastBattPercent;
    doc["batt_crate"] = lastBattCRate;

    size_t n = serializeJson(doc, txBuffer);
    digitalWrite(LED_GPIO, HIGH);
    radio.transmit(txBuffer, n);
    digitalWrite(LED_GPIO, LOW);

    radio.startReceive();
    receivedFlag = false;
}

void getTemperatureOffset() {
    Serial.println("Reading current temperature offset...");

    scd4x.stopPeriodicMeasurement();
    delay(500);

    float currentOffset = 0.0;
    int16_t ret = scd4x.getTemperatureOffset(currentOffset);

    if (ret == 0) {
        Serial.printf("Current temperature offset: %.2f °C\n", currentOffset);
    } else {
        Serial.printf("Failed to read temperature offset, error: %d\n", ret);
    }

    scd4x.startPeriodicMeasurement();

    StaticJsonDocument<256> doc;
    doc["value"] = device_name;
    doc["temp_offset_current"] = currentOffset;
    doc["temp_offset_read_success"] = (ret == 0);
    doc["co2"] = lastCO2;
    doc["temp"] = lastTemp;
    doc["hum"] = lastHum;
    doc["batt_volt"] = lastBattVolt;
    doc["batt_percent"] = lastBattPercent;
    doc["batt_crate"] = lastBattCRate;

    size_t n = serializeJson(doc, txBuffer);
    digitalWrite(LED_GPIO, HIGH);
    radio.transmit(txBuffer, n);
    digitalWrite(LED_GPIO, LOW);

    radio.startReceive();
    receivedFlag = false;
}

/* ================= ALTITUDE CALIBRATION ================= */

void setSensorAltitude(uint16_t altitudeMeters) {
    Serial.printf("Setting sensor altitude to %u meters\n", altitudeMeters);

    if (altitudeMeters > 3000) {
        Serial.println("Error: Altitude must be 0-3000 meters per SCD41 datasheet");
        return;
    }

    scd4x.stopPeriodicMeasurement();
    delay(500);

    int16_t ret = scd4x.setSensorAltitude(altitudeMeters);

    bool success = false;
    if (ret == 0) {
        Serial.printf("Altitude set to %u m\n", altitudeMeters);
        ret = scd4x.persistSettings();
        if (ret == 0) {
            Serial.println("Altitude saved to EEPROM");
            success = true;
        } else {
            Serial.printf("Failed to persist altitude, error: %d\n", ret);
        }
    } else {
        Serial.printf("Failed to set altitude, error: %d\n", ret);
    }

    delay(500);
    scd4x.startPeriodicMeasurement();

    StaticJsonDocument<256> doc;
    doc["value"] = device_name;
    doc["altitude_set"] = success;
    doc["altitude_value"] = altitudeMeters;
    doc["co2"] = lastCO2;
    doc["temp"] = lastTemp;
    doc["hum"] = lastHum;
    doc["batt_volt"] = lastBattVolt;
    doc["batt_percent"] = lastBattPercent;
    doc["batt_crate"] = lastBattCRate;

    size_t n = serializeJson(doc, txBuffer);
    digitalWrite(LED_GPIO, HIGH);
    radio.transmit(txBuffer, n);
    digitalWrite(LED_GPIO, LOW);

    radio.startReceive();
    receivedFlag = false;
}

void getSensorAltitude() {
    Serial.println("Reading current sensor altitude...");

    scd4x.stopPeriodicMeasurement();
    delay(500);

    uint16_t currentAltitude = 0;
    int16_t ret = scd4x.getSensorAltitude(currentAltitude);

    if (ret == 0) {
        Serial.printf("Current altitude: %u meters\n", currentAltitude);
    } else {
        Serial.printf("Failed to read altitude, error: %d\n", ret);
    }

    scd4x.startPeriodicMeasurement();

    StaticJsonDocument<256> doc;
    doc["value"] = device_name;
    doc["altitude_current"] = currentAltitude;
    doc["altitude_read_success"] = (ret == 0);
    doc["co2"] = lastCO2;
    doc["temp"] = lastTemp;
    doc["hum"] = lastHum;
    doc["batt_volt"] = lastBattVolt;
    doc["batt_percent"] = lastBattPercent;
    doc["batt_crate"] = lastBattCRate;

    size_t n = serializeJson(doc, txBuffer);
    digitalWrite(LED_GPIO, HIGH);
    radio.transmit(txBuffer, n);
    digitalWrite(LED_GPIO, LOW);

    radio.startReceive();
    receivedFlag = false;
}

/* ================= FORCED RECALIBRATION (FRC) ================= */

void forceSCD41Calibration(uint16_t targetCO2) {
    Serial.println("Starting Forced Recalibration...");

    uint16_t co2 = lastCO2;
    if (co2 == 0) {
        Serial.println("No valid CO2 reading available, skipping FRC");
        lastFrcStatus = "no_co2_data";
        lastFrcTime = millis();
        return;
    }

    Serial.printf("Device: %s, Current CO2: %u ppm, FRC target: %u ppm\n",
        device_name.c_str(), co2, targetCO2);

    // Brief stability wait — sensor should already be equilibrated outdoors
    // before the FRC command is sent from Node-RED
    Serial.println("Waiting 5s for sensor stability...");
    delay(5000);

    scd4x.stopPeriodicMeasurement();
    delay(500);

    uint16_t frcCorrection = 0;
    int16_t ret = scd4x.performForcedRecalibration(targetCO2, frcCorrection);

    bool frcSuccess = false;
    if (ret == 0) {
        Serial.printf("FRC success - correction value: %u\n", frcCorrection);
        ret = scd4x.persistSettings();
        if (ret == 0) {
            Serial.println("FRC calibration saved to EEPROM");
            frcSuccess = true;
            lastFrcStatus = "success";
        } else {
            Serial.printf("Failed to persist FRC, error: %d\n", ret);
            lastFrcStatus = "no_persist";
        }
    } else {
        Serial.printf("FRC FAILED - code: %d, correction: %u\n", ret, frcCorrection);
        lastFrcStatus = "failed";
    }

    lastFrcTime = millis();

    delay(500);
    scd4x.startPeriodicMeasurement();
    Serial.println("Periodic measurement restarted");

    StaticJsonDocument<256> doc;
    doc["value"]          = device_name;
    doc["co2"]            = lastCO2;
    doc["temp"]           = lastTemp;
    doc["hum"]            = lastHum;
    doc["frc_applied"]    = frcSuccess;
    doc["frc_correction"] = frcCorrection;
    doc["frc_persisted"]  = frcSuccess;
    doc["batt_volt"]      = lastBattVolt;
    doc["batt_percent"]   = lastBattPercent;
    doc["batt_crate"]     = lastBattCRate;

    size_t n = serializeJson(doc, txBuffer);
    digitalWrite(LED_GPIO, HIGH);
    int state = radio.transmit(txBuffer, n);
    digitalWrite(LED_GPIO, LOW);

    if (state == RADIOLIB_ERR_NONE) {
        Serial.println("FRC result transmitted via LoRa");
    } else {
        Serial.printf("FRC result TX failed, code: %d\n", state);
    }

    radio.standby();
    delay(10);

    int rxState = radio.startReceive();
    if (rxState != RADIOLIB_ERR_NONE) {
        Serial.printf("FRC: RX restart failed, code: %d\n", rxState);
    }
    receivedFlag = false;
}

/* ================= LORA COMMAND HANDLER ================= */
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
void loop() {
    // Check for incoming LoRa commands (interrupt-driven, non-blocking)
    handleLoRaCommand();

    // Periodic sensor read and LoRa transmission
    if (millis() - lastRead >= MEAS_INTERVAL_MS && !isTransmitting) {
        lastRead = millis();

        uint16_t co2;
        float temperature, humidity;
        float battVolt = 0.0, battPercent = 0.0, battCRate = 0.0;
        bool battValid = false;

        // Read SCD41
        if (!readSensor(co2, temperature, humidity)) {
            co2 = lastCO2;
            temperature = lastTemp;
            humidity = lastHum;
            Serial.println("Measurement not ready, using last-good values");
        } else {
            lastCO2 = co2;
            lastTemp = temperature;
            lastHum = humidity;
        }

        Serial.printf("--- %s ---\n", device_name.c_str());
        Serial.printf("CO2: %u ppm  Temp: %.2f °C  Hum: %.1f%%\n",
                     co2, temperature, humidity);

        // Read MAX17048
        if (batteryAvailable) {
            if (readBattery(battVolt, battPercent, battCRate)) {
                lastBattVolt = battVolt;
                lastBattPercent = battPercent;
                lastBattCRate = battCRate;
                battValid = true;
                Serial.printf("Battery: %.2fV  %.1f%%  C-Rate: %.2f%%/hr\n",
                             battVolt, battPercent, battCRate);
                if (battPercent <= BATTERY_CRITICAL_PERCENT) {
                    Serial.printf("🔴 CRITICAL BATTERY: %.1f%%\n", battPercent);
                } else if (battPercent <= BATTERY_WARN_PERCENT) {
                    Serial.printf("⚠️ LOW BATTERY: %.1f%%\n", battPercent);
                }
            } else {
                Serial.println("Battery read failed");
            }
        }

        String battStatus = getBatteryStatus(battPercent, battValid);

        // Build JSON payload
        StaticJsonDocument<256> doc;
        doc["value"]   = device_name;
        doc["co2"]     = co2;
        doc["temp"]    = temperature;
        doc["hum"]     = humidity;
        doc["rssi"]    = radio.getRSSI();
        doc["snr"]     = radio.getSNR();
        doc["pferror"] = 0;
        doc["batt_volt"]    = battValid ? battVolt    : 0.0;
        doc["batt_percent"] = battValid ? battPercent : 0.0;
        doc["batt_crate"]   = battValid ? battCRate   : 0.0;
        doc["batt_status"]  = battStatus;

        // Include FRC status for 60 seconds after a calibration event
        if (lastFrcStatus != "none" && (millis() - lastFrcTime) < 60000) {
            doc["last_frc_status"]  = lastFrcStatus;
            doc["last_frc_age_sec"] = (millis() - lastFrcTime) / 1000;
        }

        // Include CRC error count if non-zero (useful for diagnosing LoRa issues)
        if (crcErrors > 0) {
            doc["crc_errors"] = crcErrors;
        }

        size_t n = serializeJson(doc, txBuffer);

        // Check for any commands that arrived during the sensor read
        handleLoRaCommand();
        delay(50);
        handleLoRaCommand();

        // Async transmit — allows RX to continue while TX is in progress
        digitalWrite(LED_GPIO, HIGH);
        transmittedFlag = false;
        isTransmitting = true;
        radio.setDio1Action(setTxFlag);

        int state = radio.startTransmit(txBuffer, n);
        if (state != RADIOLIB_ERR_NONE) {
            Serial.printf("TX start failed, code: %d\n", state);
            isTransmitting = false;
            digitalWrite(LED_GPIO, LOW);
            radio.setDio1Action(setRxFlag);
            radio.startReceive();
        } else {
            Serial.println("TX started (async)...");
        }
    }

    // Handle async TX completion
    if (transmittedFlag) {
        transmittedFlag = false;
        digitalWrite(LED_GPIO, LOW);
        Serial.println("LoRa TX complete");

        radio.setDio1Action(setRxFlag);
        delay(10);
        int rxState = radio.startReceive();
        rxRestartCount++;
        if (rxState != RADIOLIB_ERR_NONE) {
            Serial.printf("RX restart failed, code: %d\n", rxState);
        }
        receivedFlag = false;
    }
}

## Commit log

2026-03-31 Added board data sheets
2026-03-31 Added Attachments folder
2026-03-31 Added Gerber files
2026-03-31 Fixed Attachment naming
2026-03-31 Added battery warnings
2026-04-25 Readme additions
    [Cable_Grommet.step, Cable_Grommet.stl, SCD41_Box_Cap_CapFace_assembly.step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]
2026-04-25 Added enclosure.md
2026-04-25 Update readme,md for enclosures link
